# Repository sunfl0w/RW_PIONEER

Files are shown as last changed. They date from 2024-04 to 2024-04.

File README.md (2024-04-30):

# RW-Pioneer

RW-Pioneer is a computer project inspired by Ben Eater's [8-bit breadboard computer project](https://www.youtube.com/playlist?list=PLowKtXNTBypGqImE405J2565dvjafglHU) over at YouTube.
I always wanted to build my own crappy computer, and the Pioneer was my first such attempt.
The design is not perfect by any means, but it was the best one I could come up with after a few semesters of studying computer science.

**Note that the RW-Pioneer is a few years old by now and I only compiled old schematics, layouts and code for this repository.**
**I recently added a binary compatible Verilog model of the system with Verilator test suite and Vivado project files for the Nexys A7 board.**

## Content

This repository contains the following schematics and software components:

- RW-Pioneer schematics, paper explaining the architecture and KiCad design files (Schematic and RW_PIONEER_WHITEPAPER.pdf)
- RW-Pioneer Verilog model with Verilator test suite and Vivado project files for the NEXYS A7 board (VerilogModel)
- HEX-Module and 1602-Module schematics and KiCad design files (ExpansionModules)
- Instruction LUT generator for the instruction decoder memory IC of the system (InstructionLUTGenerator)
- Memory-Programmer host and programmer software sources, schematics and KiCad design files (MemoryProgrammer)
- Simple software emulator for the system (RWEMU)

## Licenses

The software and schematics are licensed under the permissive BSD 3-Clause License.

## Links

[Visit my personal website to see the Pioneer in action.](https://www.rechenwerke.com/projects/rw_pioneer)

## Gallery

Image of a prototype board I assembled a few years ago.

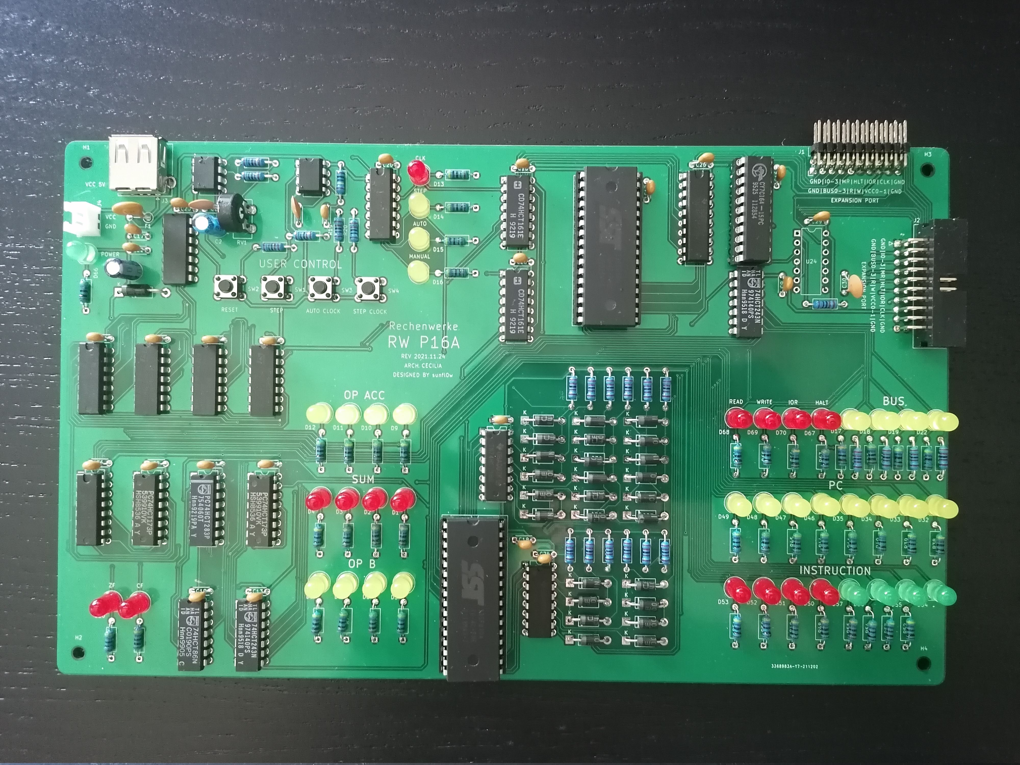
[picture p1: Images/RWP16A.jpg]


Image of the NEXYS A7 board running the RW-Pioneer Verilog model.



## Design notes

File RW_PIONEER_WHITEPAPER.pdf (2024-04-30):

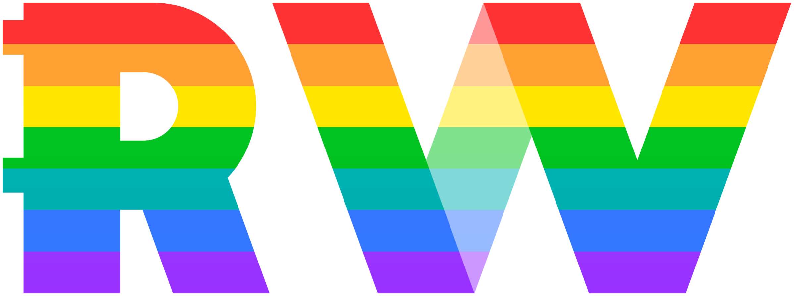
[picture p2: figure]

# Die Rechenwerke RW-Pioneer

### Luca Anthony Schwarz / Die Rechenwerke

### April 30, 2024, Hannover

1

www.rechenwerke.com

General information

The purpose of this paper is to provide an overview over the RW-Pioneer computer system. All implementation details in this paper only apply to the physical RW-Pioneer system implementation based on discrete integrated circuits and components. The Verilog-based version utilizes the same instruction set, but performs operations in three instead of two clock cycles. The changes were required to make the model synthesizable on FPGAs.

Contents

1 Architecture specification | 1
2 Hardware components | 6
3 Expansion port | 7
4 Expansion modules | 8
5 Programming | 8
6 Emulation | 9
7 Verilog model | 9
8 Schematics | 10
1 | Architecture specification
1.1 | General architecture description

RW-Pioneer is a 4-bit computer system that is based on the Harvard computer architecture. All mathematical operations are performed on 4-bit wide sets of binary data in the ALU. Wider operations are possible by using the carry flag of the previous operation. This requires strict instruction ordering, as multiple additions or subtraction operations must be executed consec-utively. RAM address space is split up into sixteen addresses. Each address corresponds to one 4-bit word of storage in RAM. Program memory consists of 256 bytes, with one instruction being encoded by two 4-bit words. The program counter (PC) can be altered by instructions to allow for jumps and branches. As memory access is only possible using immediate addresses, the system can not be considered general purpose and is not Turing-complete.

The architecture can be seen in the block diagram 1. The diagram shows all main components of the architecture with their respective connections and splits them into two groups (Step0 and Step1). Instructions are executed in two clock cycles. In the first cycle (Step0) the next instruction will be loaded into the instruction register and decoded by the instruction decoder which sets the control signal lines according to the loaded instruction. In the second cycle (Step1) the instruction is then executed and the step counter resets to zero while the program counter advances by 1 if no jump instruction was performed. Jump instructions write into the program counter directly without incrementing it by 1.

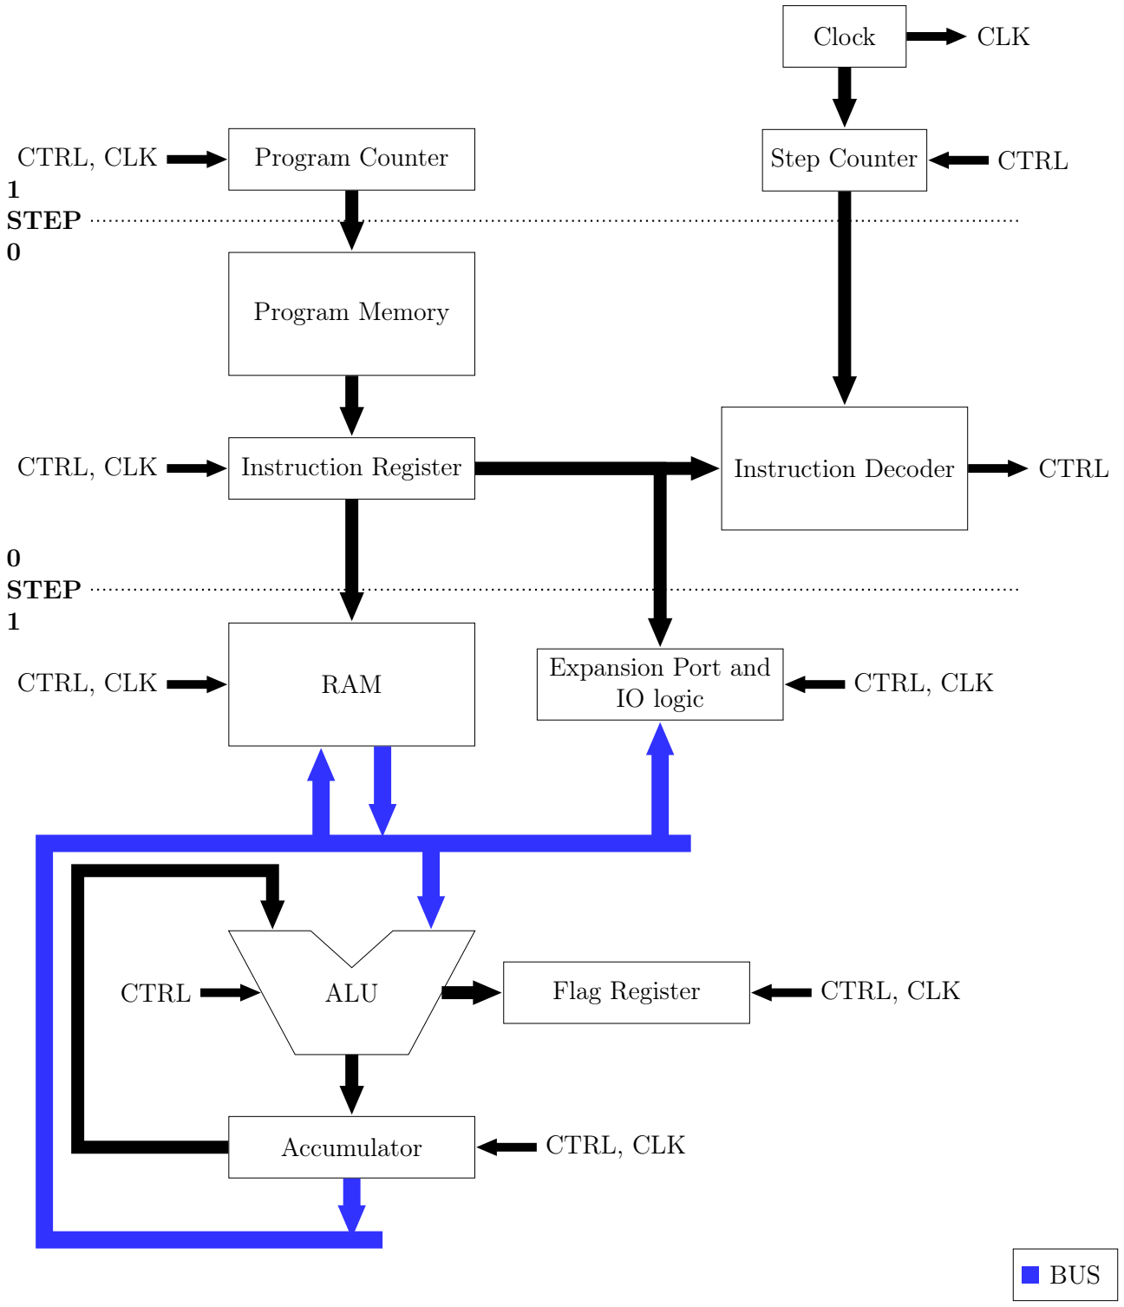
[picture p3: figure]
Program Counter; Program Memory; Instruction Register; Instruction Decoder; Step Counter; Clock; RAM; Expansion Port and; IO logic; ALU; Flag Register; Accumulator; CLK; CTRL; CTRL, CLK; 1 STEP 0; 0 STEP 1; BUS

Figure 1: DLC1 architecture block diagram

1.2 Instruction set

Instructions are encoded into one byte of data. The most significant word is called instruction code (IC) and the least significant word is called instruction value (IV). The instruction code defines the instruction type, and the instruction value is the immediate parameter of that instruction.
7 | 4 | 3 | 0
Instruction Code IC | Instruction Value IV

Figure 2: Instruction Bit Field

As four bits are used to encode an instruction’s code, a maximum of 16 different instructions are supported. The implemented instructions are listed in table 1. Not all instructions require an instruction value. It is advised to use an instruction value of 0xF in such cases.

RW-PIONEER instruction set

Instruction | IC | Functional description
LDI | 0x0 | ACC 7→IV
LDA | 0x1 | ACC 7→RAM[IV]
STOA | 0x2 | RAM[IV] 7→ACC
STOB | 0x3 | RAM[IV] 7→BUS
ADD | 0x4 | ACC 7→ACC + RAM[IV]
ADDI | 0x5 | ACC 7→ACC + IV
ADDC | 0x6 | ACC 7→ACC + RAM[IV] + CF
SUB | 0x7 | ACC 7→ACC − RAM[IV]
SUBI | 0x8 | ACC 7→ACC − IV
SUBC | 0x9 | ACC 7→ACC − RAM[IV] − CF
SJMP | 0xA | PCL 7→IV
JMP | 0xB | PCL 7→IV and PCH 7→ACC
BNEZ | 0xC | PCL 7→IV and PCH 7→ACC if ZF = LOW
BEZ | 0xD | PCL 7→IV and PCH 7→ACC if ZF = HIGH
HALT | 0xE | Halt program execution (set HLT signal HIGH)
NOOP | 0xF | Perform no operation

Table 1: RW-Pioneer instruction set

1.3 Micro operations

Instruction codes are interpreted by an instruction decoder. The decoder then supplies the ALU and the memory unit with appropriate control signals, so-called micro operations. Interestingly, the memory unit controls the instruction and random access memories, as well as the program counter. The instruction counter is enabled or disabled by the CE signal, and the system is halted by the HLT signal. The ALU performs the mathematical operations and controls the accumulator and flag registers. The control signals are influenced by the step counter, as the system requires two cycles per instruction. In step 0 a new instruction is loaded in all cases. Only in step 1 the fetched instruction is interpreted and executed. Conditional branches are only executed, if the stored zero flag value ZF is a match for the given branch instruction. For example, to take the branch on an BNEZ instruction, the ZF signal is required to be LOW. The internal control signals and micro operations are listed in table 2.

RW-Pioneer instruction to micro instruction look-up table
Instruction | Step | ZF | ALU | MEM | CE | HLT
X | 0 | X | ALU_NOOP | MEM_LDINSTRC | L | L
LDI | 1 | X | ALU_BUSTOACC | MEM_IVTOBUS | H | L
LDA | 1 | X | ALU_BUSTOACC | MEM_RAMTOBUS | H | L
STOA | 1 | X | ALU_ACCTOBUS | MEM_BUSTORAM | H | L
STOB | 1 | X | ALU_NOOP | MEM_BUSTORAM | H | L
ADD | 1 | X | ALU_ADD | MEM_RAMTOBUS | H | L
ADDI | 1 | X | ALU_ADD | MEM_IVTOBUS | H | L
ADDC | 1 | X | ALU_ADDC | MEM_RAMTOBUS | H | L
SUB | 1 | X | ALU_SUB | MEM_RAMTOBUS | H | L
SUBI | 1 | X | ALU_SUB | MEM_IVTOBUS | H | L
SUBC | 1 | X | ALU_SUBC | MEM_RAMTOBUS | H | L
SJMP | 1 | X | ALU_NOOP | MEM_SJMP | L | L
JMP | 1 | X | ALU_NOOP | MEM_JMP | L | L
BNEZ | 1 | L | ALU_NOOP | MEM_JMP | L | L
BNEZ | 1 | H | ALU_NOOP | MEM_NOOP | H | L
BEZ | 1 | L | ALU_NOOP | MEM_NOOP | H | L
BEZ | 1 | H | ALU_NOOP | MEM_JMP | L | L
HALT | 1 | X | ALU_NOOP | MEM_NOOP | L | H
NOOP | 1 | X | ALU_NOOP | MEM_NOOP | H | L

Table 2: RW-Pioneer instruction to micro instruction look-up table

The ALU is supplied with a single micro operation per step by the instruction decoder. The micro operation is supplied as a 3-bit wide signal (AIC), which is then interpreted by the ALU as described in table 3. The ALU micro instruction decoder directly controls ALU operation by using six internal control signals. The signals AI0 and AI1 define, whether an addition or a subtraction is performed and if this operation uses the currently stored carry flag. ACCTBUS controls if the accumulator value is to be sent on the system bus. SSACC defines the accumulator source. This can be the system bus, or the result of the ALU. EACC disables the accumulator register and FI disables storing the zero and the carry flags for an operation. The memory unit is supplied with a single micro operation per step by the instruction

RW-Pioneer ALU micro instructions
Micro instruction | AIC | AI1 | AI0 | ACCTBUS | SSACC | EACC | FI
ALU_ADD | 0x0 | L | L | H | L | L | L
ALU_ADDC | 0x1 | L | H | H | L | L | L
ALU_SUB | 0x2 | H | L | H | L | L | L
ALU_SUBC | 0x3 | H | H | H | L | L | L
ALU_BUSTOACC | 0x4 | H | H | H | H | L | H
ALU_ACCTOBUS | 0x5 | H | H | L | H | H | H
ALU_NOOP | 0x6 | H | H | H | H | H | H
ALU_NOOP | 0x7 | H | H | H | H | H | H

Table 3: RW-Pioneer ALU micro instructions

decoder. The micro operation is supplied as a 3-bit wide signal (MIC), which is then interpreted by the memory unit as described in table 4. The memory unit micro instruction decoder directly controls memory, bus and program counter operations by using six internal control signals. JL disables loading the least significant four bits of the program counter from the instruction value of the current instruction. JH disables loading the most significant four bits of the program counter from the accumulator. LI disables loading the next instruction. This is only used in
step 0 to load the next instruction. WERAM sets the write enable signal of RAM. CERAM sets the chip enable signal of RAM. IVTBUS disables putting the instruction value of the current instruction to the system bus.

RW-Pioneer memory micro instructions
Micro instruction | MIC | JL | JH | LI | WERAM | CERAM | IVTBUS
MEM_SJMP | 0x0 | L | H | H | H | H | H
MEM_JMP | 0x1 | L | L | H | H | H | H
MEM_BUSTORAM | 0x2 | H | H | H | L | L | H
MEM_RAMTOBUS | 0x3 | H | H | H | H | L | H
MEM_IVTOBUS | 0x4 | H | H | H | H | H | L
MEM_LDINSTRC | 0x5 | H | H | L | H | H | H
MEM_NOOP | 0x6 | H | H | H | H | H | H
MEM_NOOP | 0x7 | H | H | H | H | H | H

Table 4: RW-Pioneer memory micro instructions

2 Hardware components

RW-Pioneer was designed with simplicity as the primary goal. Therefore, commonly available components were chosen for physical implementation. For timing, the 555 timer ICs were used. Program memory and the instruction decoder’s look-up table use the SST39SD010A IC. It is a cheap parallel FLASH IC that is also easy to program using microcontrollers. Both memories should never be directly soldered to the PCB, as sockets make programming the memory ICs way easier. The RAM is realized by the CY7C164 chip, which is the only rare component in the whole design. All logic functions are implemented with the 74HC-Series and 74HCT-Series logic chips. 74LS ICs are not supported, but might still work.
Passive components can be chosen freely as long as the correct values are used. For example, the 1N4001 diodes may also be replaced by 1N4007 diodes or comparable ones if necessary, as long as the forward voltage drop remains at roughly 0.7 volts. The resistor values for all resistors used in conjunction with LEDs may be chosen freely as long as the resistor value is high enough. When using different color LEDs different values for different colors might be used to keep a balance of apparent brightness between them.

3 Expansion port

The RW-Pioneer provides an expansion port (also called user port) to communicate with external circuitry. The pin assignments of the expansion port are listed in table 5. The port allows access to the instruction value of the current instruction and also to the data on the system bus. Instructions interfacing with system RAM can be identified by reading the values of the R, W and IOR signals. Access is also provided to the MR, HLT and CLK signals. Sending data and receiving data over the port is done via memory mapping. When the system writes data to memory W will be HIGH and when reading R will be HIGH. IOR is HIGH when main memory is accessed in the address range 11xx2. All signals provide by the port are 5V CMOS compatible. The expansion port allows for powering the connected external device, if the power requirement does not exceed the capabilities of the system’s power supply.

RW-Pioneer expansion port pin assignment
Pins | Function
1, 2, 19, 20 | GND
15, 17 | VCC
4, 6, 8, 10 | IV of current instruction from LSB to MSB
3, 5, 7, 9 | BUS from LSB to MSB
11 | RE. HIGH when reading from RAM
12 | MR. HIGH if reset signal provided
13 | WR. HIGH when writing to RAM
14 | HLT. HIGH when halt signal is provided
16 | IOR. HIGH when RAM is accessed from addresses 11002 to 11112
18 | CLK. Direct link to the CLK signal

Table 5: RW-Pioneer expansion port pin assignment

3.1 Sending data over the expansion port

Sending data should be implemented via memory mapping. To showcase this a 4-bit register (74HC173) is connected to the expansion port which is mapped to RAM address 11112. The CLK signal is connected to the CLK input of the 4-bit register. The enable signal (E) (active

HIGH) is connected to logic that computes E = IV0 ∧ IV1 ∧ IOR and the input data lines (D0 to D3) of the register are connected to BUS (BUS0 to BUS3). When the system executes the STOA instruction with IV = 11112, the values in the accumulator will be written to RAM at address IV. The input E of the register will transition to HIGH, so the register is enabled. Then the CLK signal transitions to HIGH and the register will store the value that was on the BUS (which was also written to RAM). In conclusion, this setup links the register connected via the expansion port to a RAM address. Expansions like a simple LCD can be controlled in this way.

3.2 Receiving data over the expansion port

Receiving data should be implemented via memory mapping like sending data. The difference to sending is, that receiving data requires the STOB instruction, to first store the data at a given address in RAM. Clever memory mapping schemes would allow for direct accessing of external data, but the RW-Pioneer does not have such functionality. To showcase receiving data, a 4-bit register (74HC173) is connected to the expansion port, which is mapped to address memory address 11112. The CLK signal is connected to the CLK input of the 4-bit register. The output enable signal OE (active HIGH) is connected to logic that computes OE = IV0 ∧ IV1 ∧ IOR and the output data lines (Q0

| to Q3 ) of the register are connected to BUS (BUS0 to BUS3).
When the system executes the STOB instruction with IV = 11112, the values on the BUS will be written to RAM at address IV. The OE input of the register will transition to HIGH, so the register will write its stored value to the BUS. As a result, RAM will store the register’s stored value at the address 11112. In conclusion, this setup links the register connected via the expansion port to a RAM address. Expansions like a very simple sensor module can be realized using this memory mapping method.
4 | Expansion modules
4.1 | HEX-Module

The HEX-Module provides the system with four seven-segment displays to display four-digit hexadecimal values. Each digit’s value is dependent on the value the accompanying register stores. The registers are directly writable by the RW-Pioneer.

4.2 1602-Module

The 1602-Module expands the system with a 1602-LCD, that is completely controllable by the RW-Pioneer. With the module, it is quite easy to display small texts and numbers.

5 Programming

The system is programmed by writing instructions to the instruction memory chip. A simple memory programmer called Memory-Programmer is provided with the RW-Pioneer to fulfill this task. The programmer employs an ATmega328 microcontroller in the form of an Arduino Nano and is controlled by a USB host through a simple host software. The host computer simply specifies a hex file to program to memory, and the memory programmer will complete this task in a few seconds.

6 Emulation

A simple emulation software called RWEMU for the RW-Pioneer is supplied alongside schematics and this document. With this emulator, programs can be tested before running them on a physical design. This helps to eliminate errors introduced by the programmer but can also be used to verify the physical design by comparing emulation and measured/observed results.

7 Verilog model

Parts of the RW-Pioneer system are modeled in the Verilog HDL. This model is supplied alongside this document and implements all essential components, except the manual clocking mechanism and the expansion port. The model and the physical implementation are binary compatible.

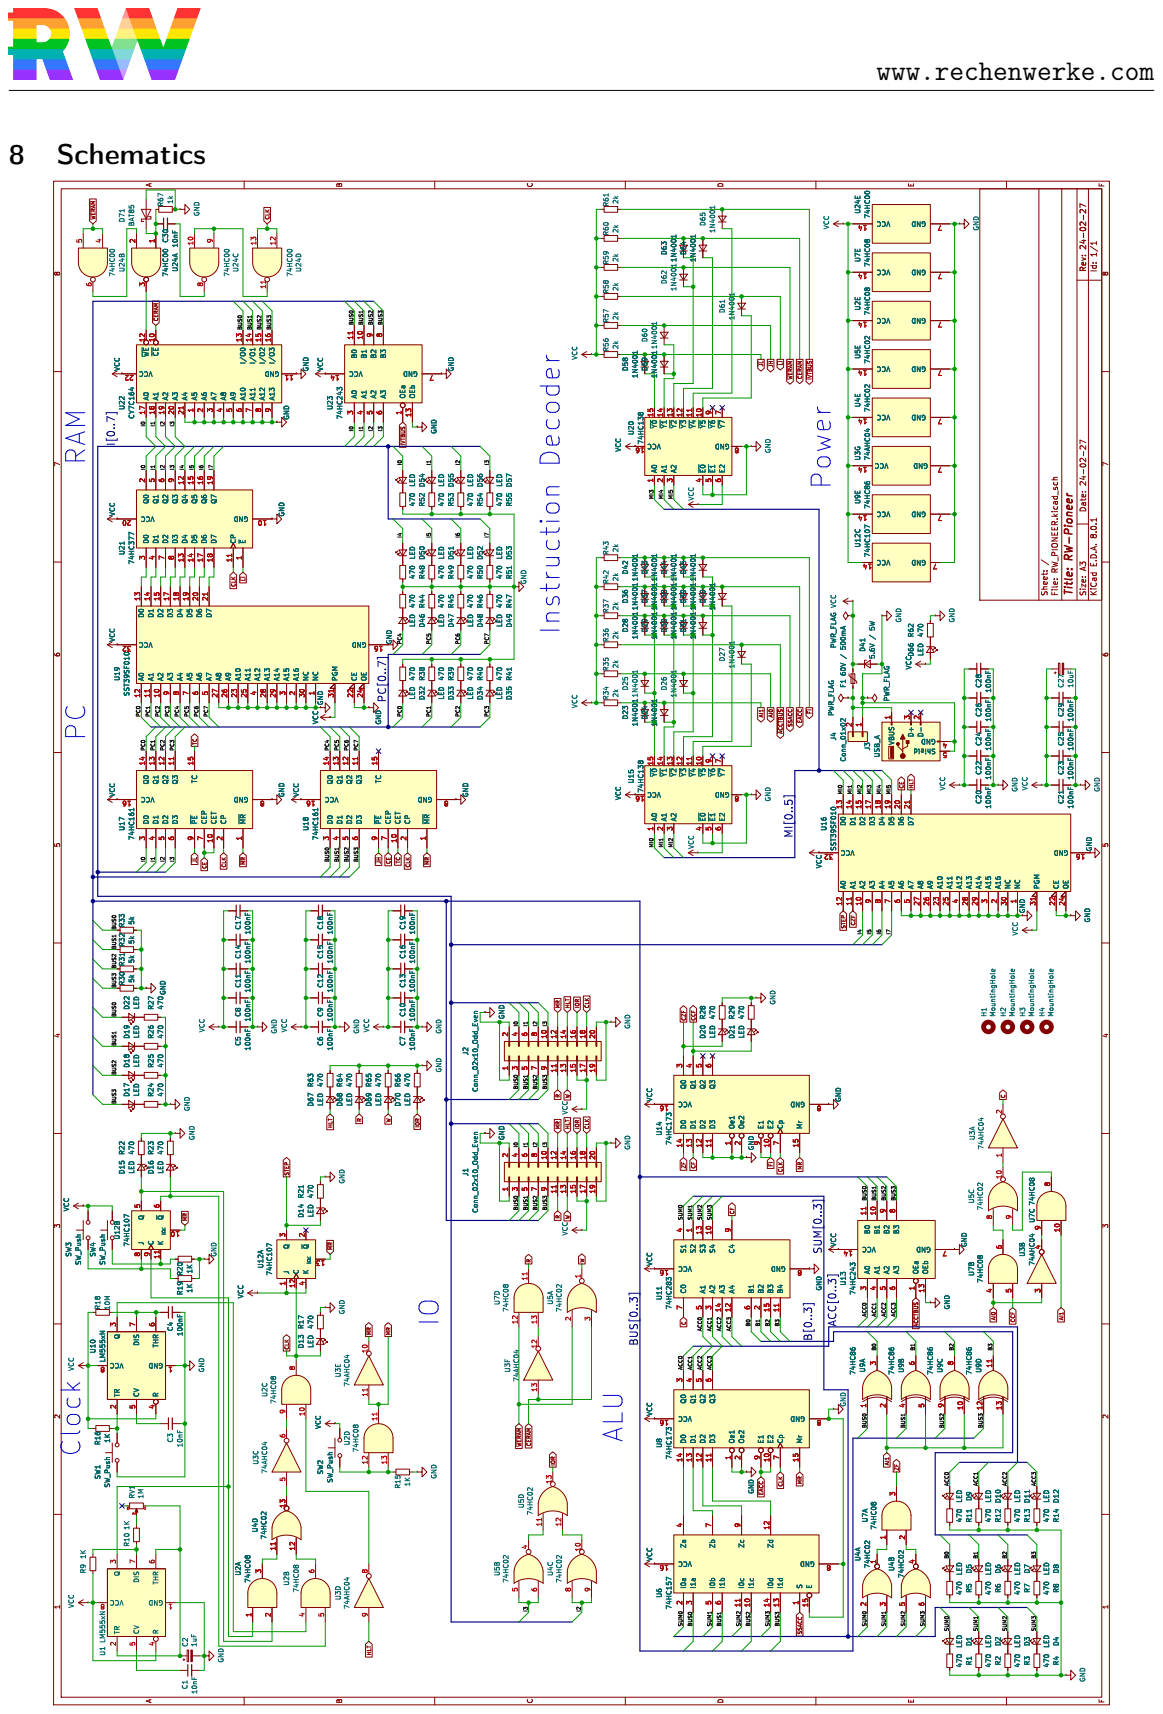
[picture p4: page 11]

F Date: 24-02-27 KiCad E.D.A. 8.0.1 Rev: 24-02-27 Size: A3

~{FI} CLK HLT CLK

2k VCC GND VCC 14 GND

Id: 1/1 Title: RW-Pioneer File: RW_PIONEER.kicad_sch Sheet: / PWR_FLAG

74HC377~{E} 1 GND 10 CP 11 Q4 12 D4 13 D5 14 Q5 15 Q6 16 D6 17 D7 18 Q7 19 Q0 2 VCC 20 D0 3 D1 4 Q1 5 Q2 6 D2 7 D3 8 Q3 9 VCC GND GND

~{JH} ~{LI} ~{CERAM} ~{JL} ~{WERAM} ~{IVTBUS}

U19 SST39SF010 GND 16 VCC 32 NC 1 A2 10 A1 11 A0 12 D0 13 D1 14 D2 15 D3 17 D4 18 D5 19 A16 2 D6 20 D7 21 CE 22 A10 23 OE 24 A11 25 A9 26 A8 27 A13 28 A14 29 A15 3 NC 30 PGM 31 A12 4 A7 5 A6 6 A5 7 A4 8 A3 9 U23

F1 60V / 500mA GND GND VCC 14 GND

100nF GND 16 VCC 32 NC 1 A2 10 A1 11 A0 12 D0 13 D1 14 D2 15 D3 17 D4 18 D5 19 A16 2 D6 20 D7 21 CE 22 A10 23 OE 24 A11 25 A9 26 A8 27 A13 28 A14 29 A15 3 NC 30 PGM 31 A12 4 A7 5 A6 6 A5 7 A4 8 A3 9 U19 SST39SF010 C15

~{MR} 1 CET 10 Q3 11 Q2 12 Q1 13 Q0 14 TC 15 VCC 16 CP 2 D0 3 D1 4 D2 5 D3 6 CEP 7 GND

74HC161 ~{MR} 1 CET 10 Q3 11 Q2 12 Q1 13 Q0 14 TC 15 VCC 16 CP 2 D0 3 D1 4 D2 5 D3 6 CEP 7 GND

VCC GND 16 VCC 32 NC 1 A2 10 A1 11 A0 12 D0 13 D1 14 D2 15 D3 17 D4 18 D5 19 A16 2 D6 20 D7 21 CE 22 A10 23 OE 24 A11 25 A9 26 A8 27 A13 28 A14 29 A15 3 NC 30 PGM 31 A12 4 A7 5 A6 6 A5 7 A4 8 A3 9 U16 SST39SF010

U16 SST39SF010 GND 16 VCC 32 NC 1 A2 10 A1 11 A0 12 D0 13 D1 14 D2 15 D3 17 D4 18 D5 19 A16 2 D6 20 D7 21 CE 22 A10 23 OE 24 A11 25 A9 26 A8 27 A13 28 A14 29 A15 3 NC 30 PGM 31 A12 4 A7 5 A6 6 A5 7 A4 8 A3 9 GND GND

100nF GND Oe1 1 E2 10 D3 11 D2 12 D1 13 D0 14 Mr 15 VCC 16 Oe2 2 Q0 3 Q1 4 Q2 5 Q3 6 Cp 7 GND

H1 MountingHole H2 MountingHole H4 MountingHole VCC

74HC173 VCC OEa 1 B1 10 B0 11 OEb 13 VCC 14 A0 3 A1 4 A2 5 A3 6 GND

VCC GND GND Oe1 1 E2 10 D3 11 D2 12 D1 13 D0 14 Mr 15 VCC 16 Oe2 2 Q0 3 Q1 4 Q2 5 Q3 6 Cp 7 GND

74HC173 Oe1 1 E2 10 D3 11 D2 12 D1 13 D0 14 Mr 15 VCC 16 Oe2 2 Q0 3 Q1 4 Q2 5 Q3 6 Cp 7 GND

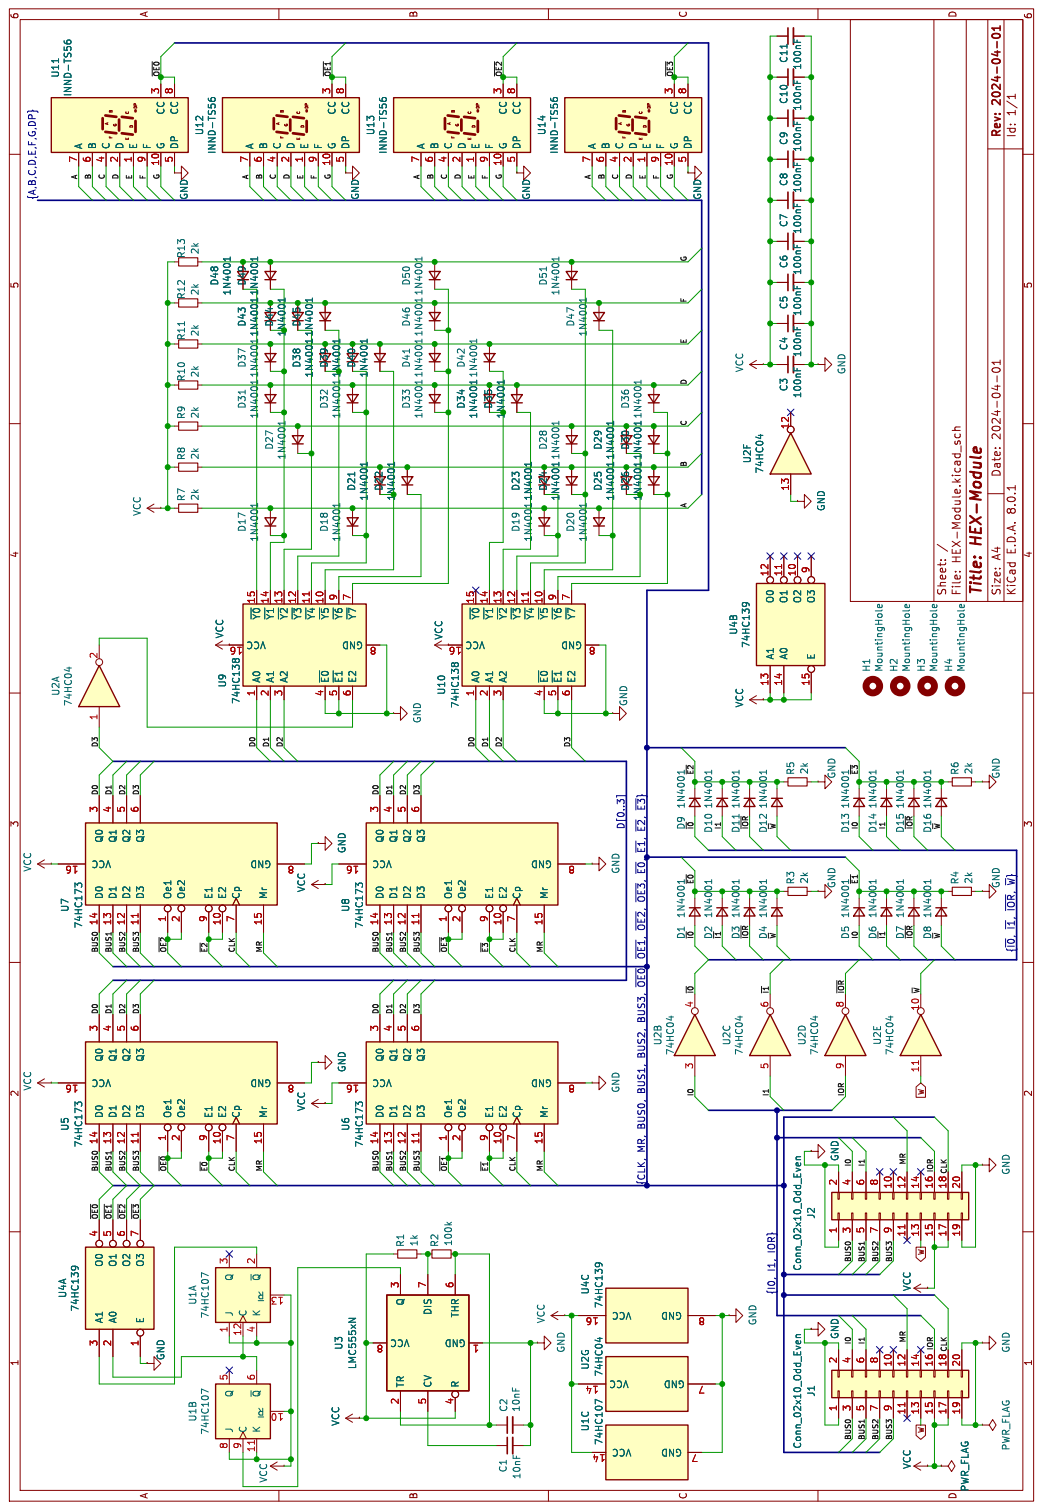
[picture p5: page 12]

D Date: 2024-04-01 KiCad E.D.A. 8.0.1 Rev: 2024-04-01 Size: A4

Id: 1/1 Title: HEX-Module

1N4001 VCC GND Oe1 1 E2 10 D3 11 D2 12 D1 13 D0 14 Mr 15 VCC 16 Oe2 2 Q0 3 Q1 4 Q2 5 Q3 6 Cp 7 GND

1N4001 GND Oe1 1 E2 10 D3 11 D2 12 D1 13 D0 14 Mr 15 VCC 16 Oe2 2 Q0 3 Q1 4 Q2 5 Q3 6 Cp 7 GND

File: HEX-Module.kicad_sch Sheet: / GND

2k D16 1N4001 H1 MountingHole H2 MountingHole H3 MountingHole H4 MountingHole VCC

VCC GND Oe1 1 E2 10 D3 11 D2 12 D1 13 D0 14 Mr 15 VCC 16 Oe2 2 Q0 3 Q1 4 Q2 5 Q3 6 Cp 7 GND

74HC173Oe1 1 E2 10 D3 11 D2 12 D1 13 D0 14 Mr 15 VCC 16 Oe2 2 Q0 3 Q1 4 Q2 5 Q3 6 Cp 7 GND

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

J1 Conn_02x10_Odd_Even GND GND VCC 14 GND

4 CV 5 THR 6 DIS 7 VCC

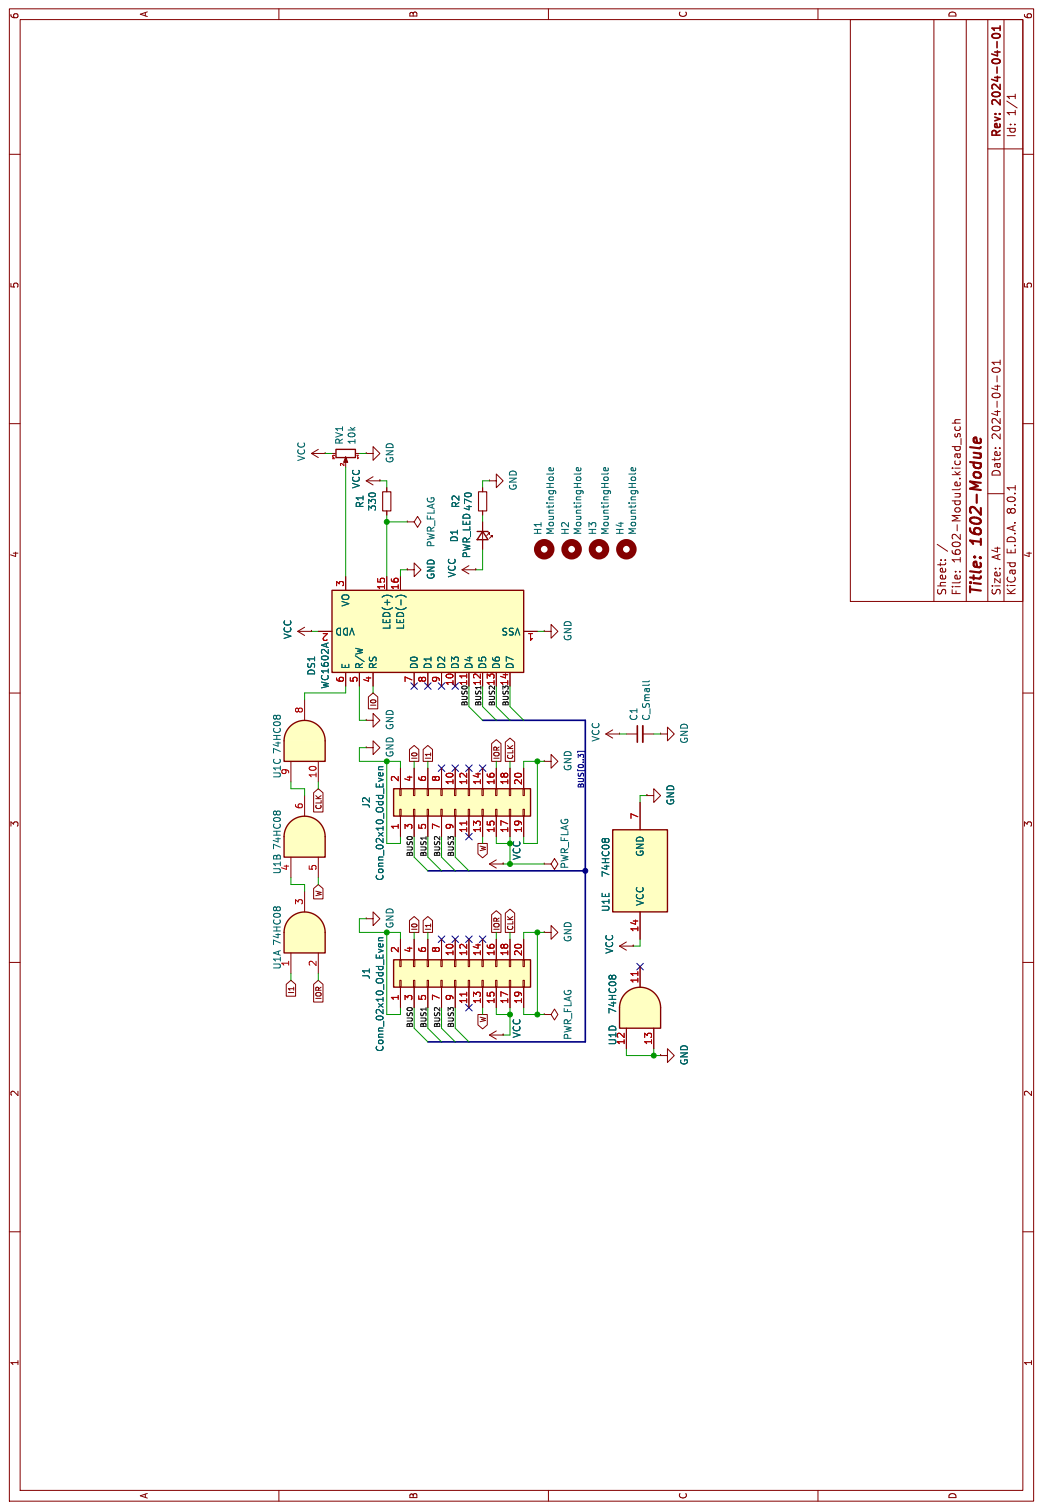
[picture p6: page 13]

D Date: 2024-04-01 KiCad E.D.A. 8.0.1 Rev: 2024-04-01 Size: A4

H1 MountingHole H2 MountingHole H3 MountingHole H4 MountingHole VCC GND

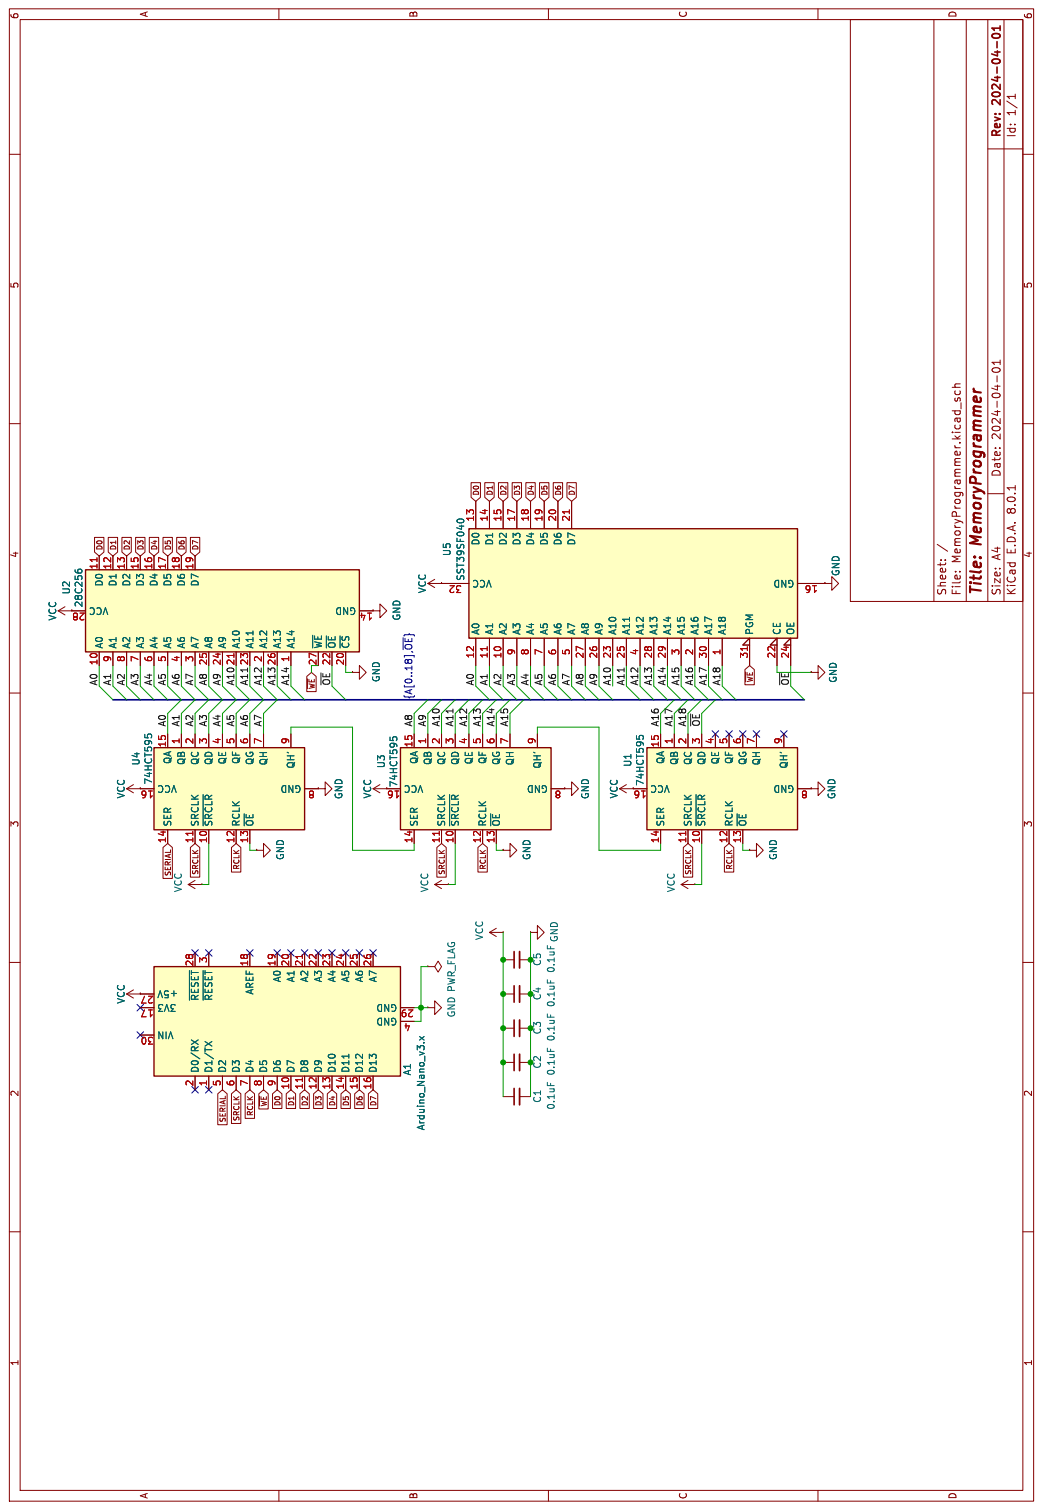
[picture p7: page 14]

D Date: 2024-04-01 KiCad E.D.A. 8.0.1 Rev: 2024-04-01 Size: A4

Id: 1/1 Title: MemoryProgrammer File: MemoryProgrammer.kicad_sch Sheet: / C2

28C256 VCCGND 16 VCC 32 A18 1 A2 10 A1 11 A0 12 D0 13 D1 14 D2 15 D3 17 D4 18 D5 19 A16 2 D6 20 D7 21 CE 22 A10 23 OE 24 A11 25 A9 26 A8 27 A13 28 A14 29 A15 3 A17 30 PGM 31 A12 4 A7 5 A6 6 A5 7 A4 8 A3 9 U5 SST39SF040 GND

U5 SST39SF040 GND 16 VCC 32 A18 1 A2 10 A1 11 A0 12 D0 13 D1 14 D2 15 D3 17 D4 18 D5 19 A16 2 D6 20 D7 21 CE 22 A10 23 OE 24 A11 25 A9 26 A8 27 A13 28 A14 29 A15 3 A17 30 PGM 31 A12 4 A7 5 A6 6 A5 7 A4 8 A3 9 GND GND GND GND GND GND

A14 1 A0 10 D0 11 D1 12 D2 13 GND 14 D3 15 D4 16 D5 17 D6 18 D7 19 A12 2 ~{CS} 20 A10 21 ~{OE} 22 A11 23 A9 24 A8 25 A13 26 ~{WE} 27 VCC 28 A7 3 A6 4 A5 5 A4 6 A3 7 A2 8 A1 9 U2

28C256 A14 1 A0 10 D0 11 D1 12 D2 13 GND 14 D3 15 D4 16 D5 17 D6 18 D7 19 A12 2 ~{CS} 20 A10 21 ~{OE} 22 A11 23 A9 24 A8 25 A13 26 ~{WE} 27 VCC 28 A7 3 A6 4 A5 5 A4 6 A3 7 A2 8 A1 9 U4

{A[0..18],~{OE}} A0 A3 A7A12 A1A6A7A8A12 A13 A17 A18 A10 A11 A5A11 A5 ~{OE} A8 A10 A9A16 ~{OE} A6A4A5 A7A14 A15 A0 A4 A2A3 GND

~{WE} D4 D5 ~{WE} D6 SRCLKD2 D3 SERIAL SRCLK

VCC QB 1 ~{SRCLR} 10 SRCLK 11 RCLK 12 ~{OE} 13 SER 14 QA 15 VCC 16 QC 2 QD 3 QE 4 QF 5 QG 6 QH 7 GND

74HCT595 QB 1 ~{SRCLR} 10 SRCLK 11 RCLK 12 ~{OE} 13 SER 14 QA 15 VCC 16 QC 2 QD 3 QE 4 QF 5 QG 6 QH 7 GND

GND GND GND QB 1 ~{SRCLR} 10 SRCLK 11 RCLK 12 ~{OE} 13 SER 14 QA 15 VCC 16 QC 2 QD 3 QE 4 QF 5 QG 6 QH 7 GND

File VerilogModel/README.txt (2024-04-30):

The 'Model' directory contains the Verilog model of the RW-Pioneer.
'RW_PIONEER_Vivado' contains a Vivado project file for the NEXYS A7 board to run the model on FPGA hardware.
'Programs' contains a memory file with a program to run when implementing the design on the NEXYS A7.

Run make test in the 'Model' directory to run a full the of the RW-Pioneer model using Verilator.
Note that google test must be installed to run the tests.

NOTICE: When running the test comment out the line that says '`define NEXYSA7' in 'Model/rtl/defines.vh'. When synthesizing the model for the NEXYSA7 uncomment the line.

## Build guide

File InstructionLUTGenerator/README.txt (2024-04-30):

Simple program to generate a binary file with the contents of the instruction decoder look-up table.
The table needs to be programmed to the instruction decoder FLASH IC for the system to function.

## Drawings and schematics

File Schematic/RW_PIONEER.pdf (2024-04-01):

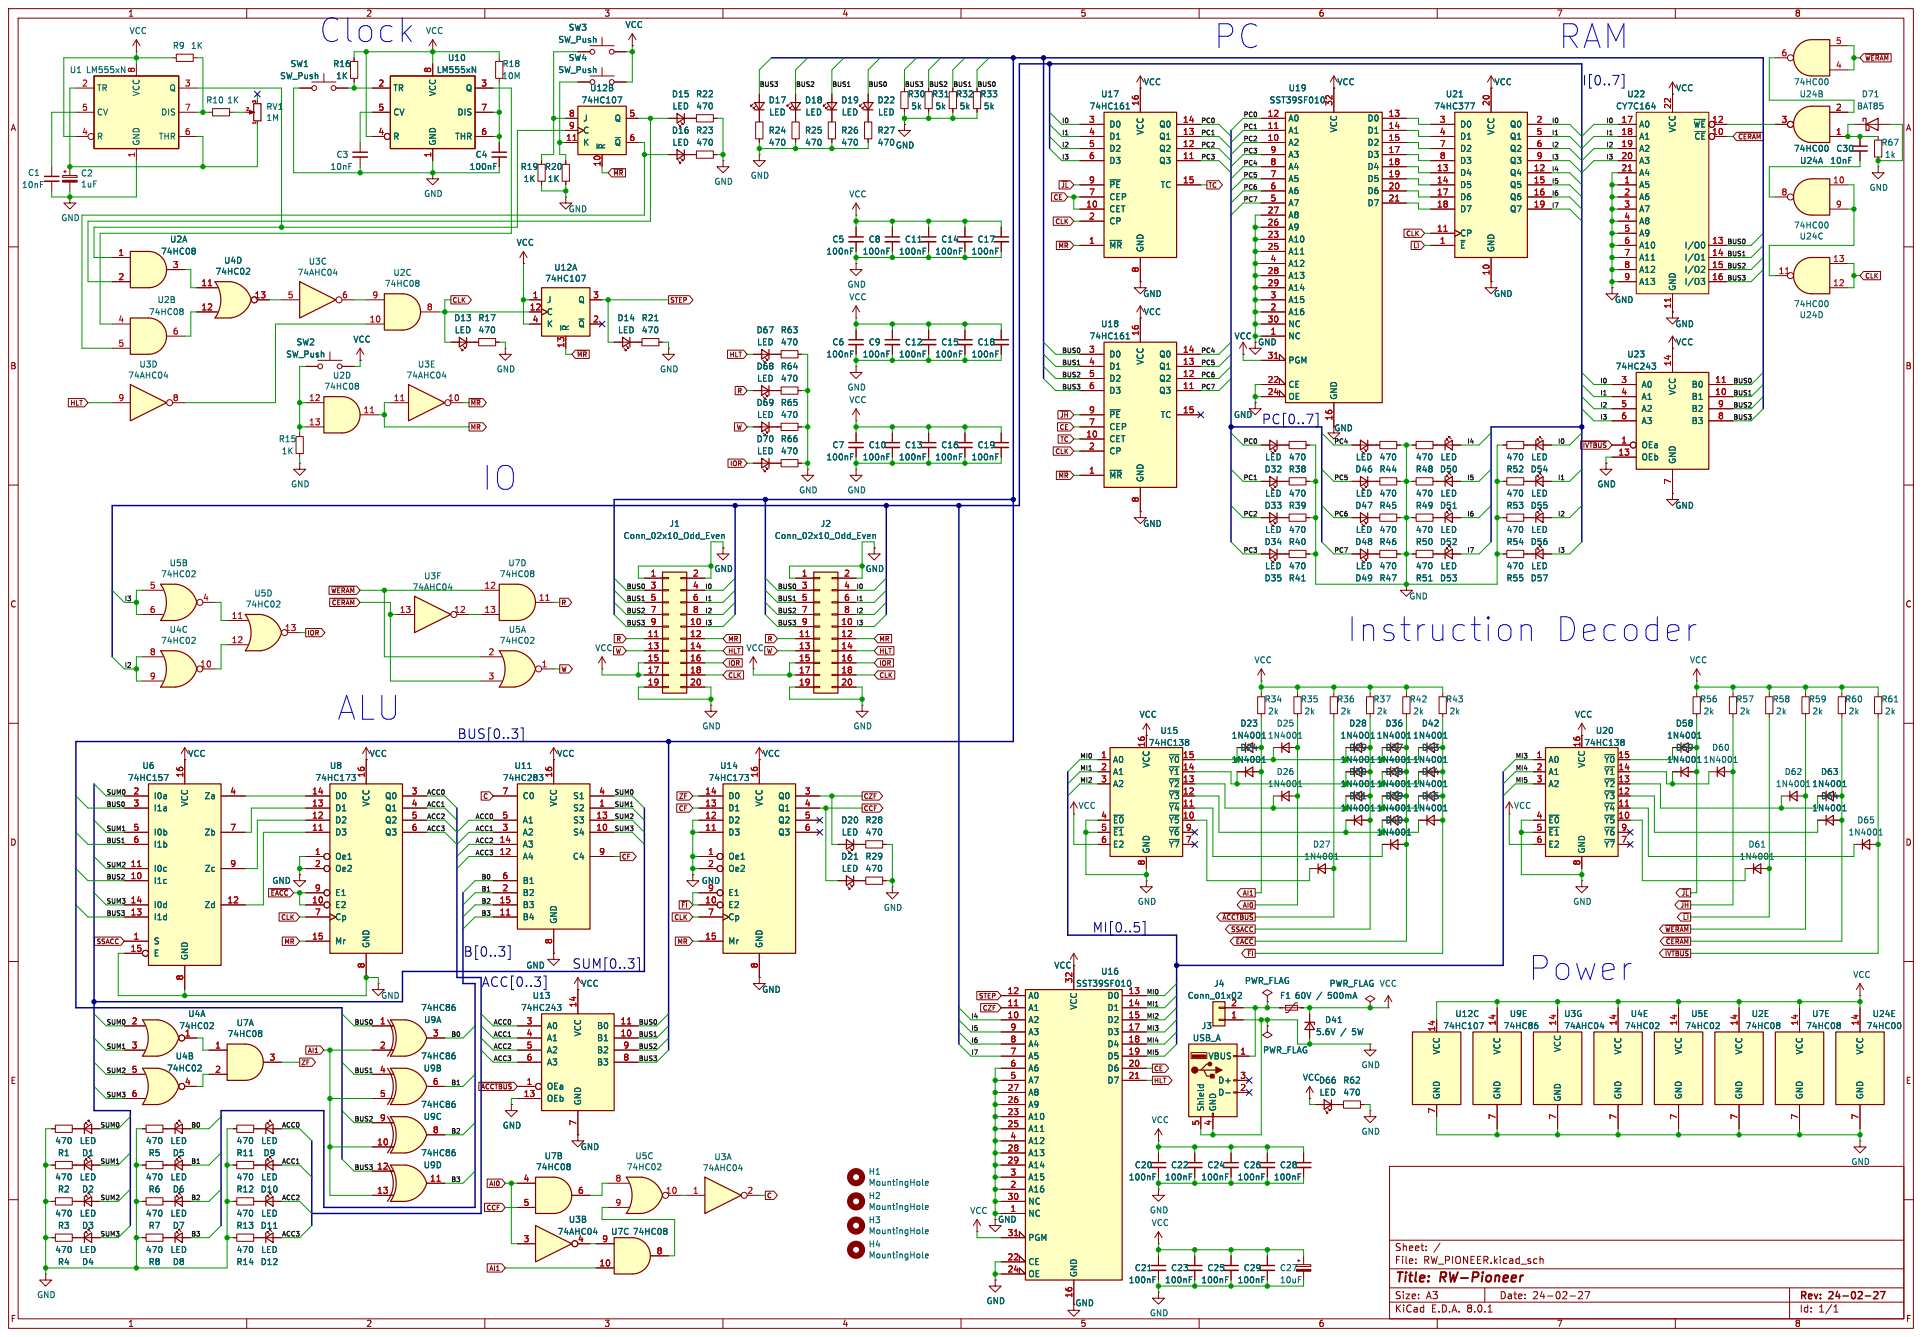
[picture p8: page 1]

~{JH} ~{LI} ~{CERAM} ~{JL} ~{WERAM} ~{IVTBUS}
Power

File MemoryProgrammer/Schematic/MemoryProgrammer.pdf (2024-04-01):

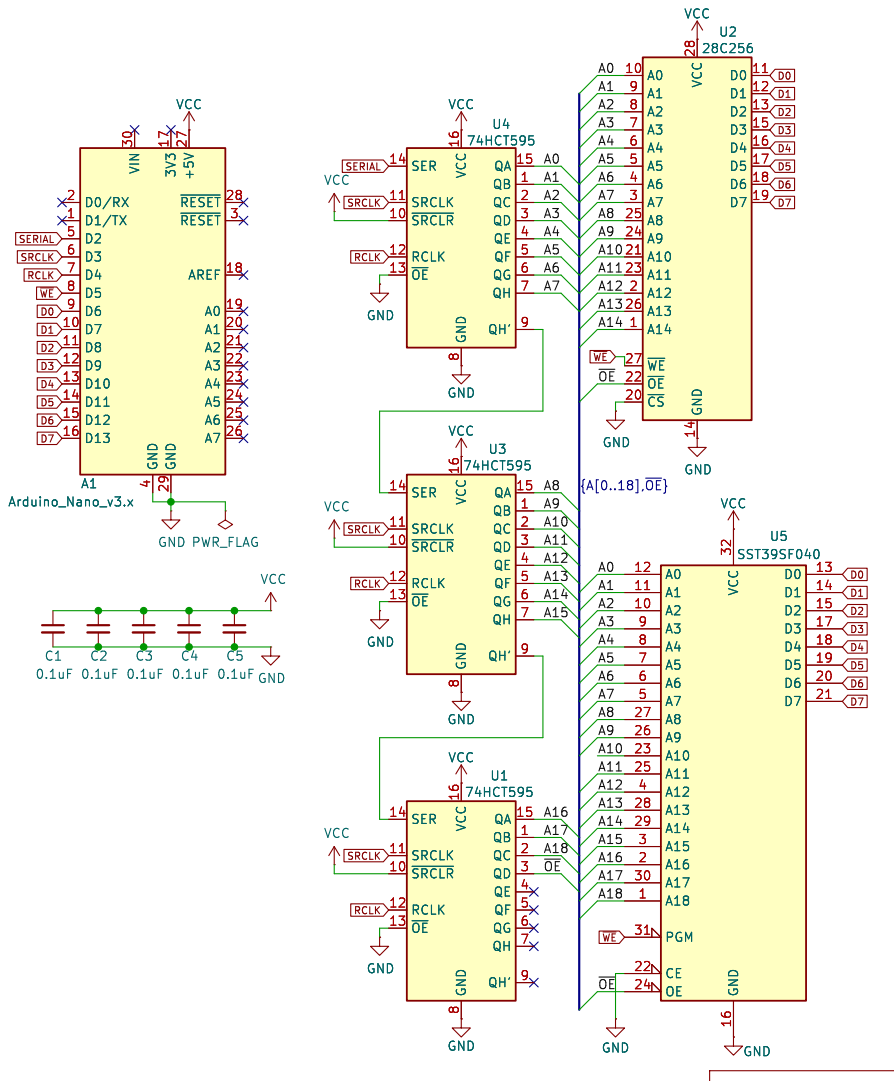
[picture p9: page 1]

Id: 1/1 Title: MemoryProgrammer File: MemoryProgrammer.kicad_sch Sheet: / C2

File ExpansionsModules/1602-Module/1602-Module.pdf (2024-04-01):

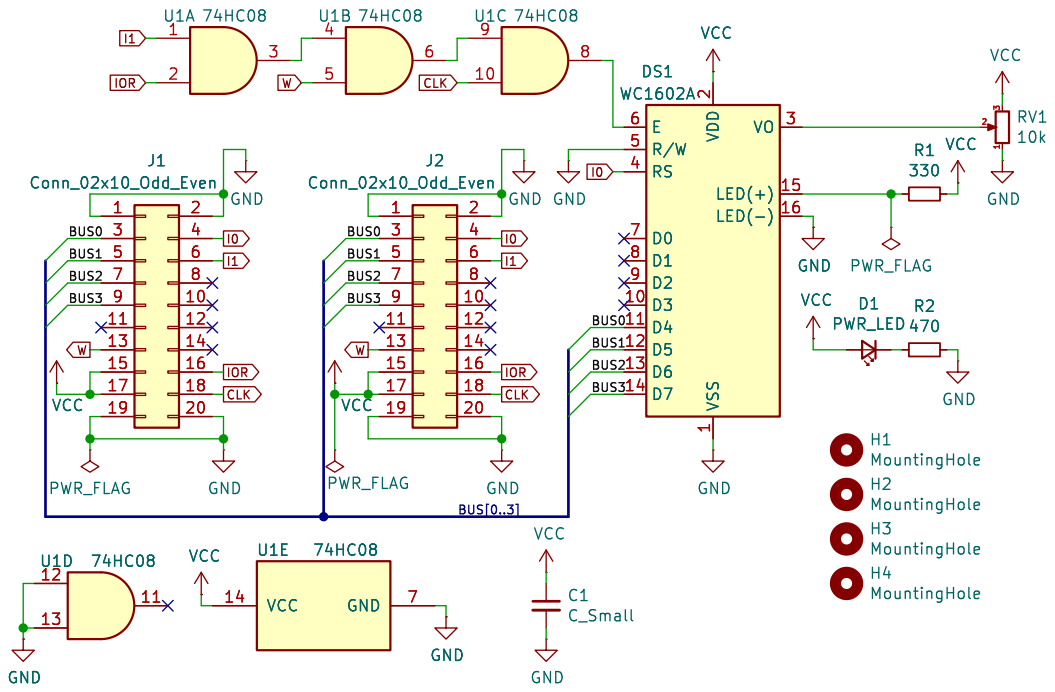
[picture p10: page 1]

H2 MountingHole H3 MountingHole H4 MountingHole H1 MountingHole GND

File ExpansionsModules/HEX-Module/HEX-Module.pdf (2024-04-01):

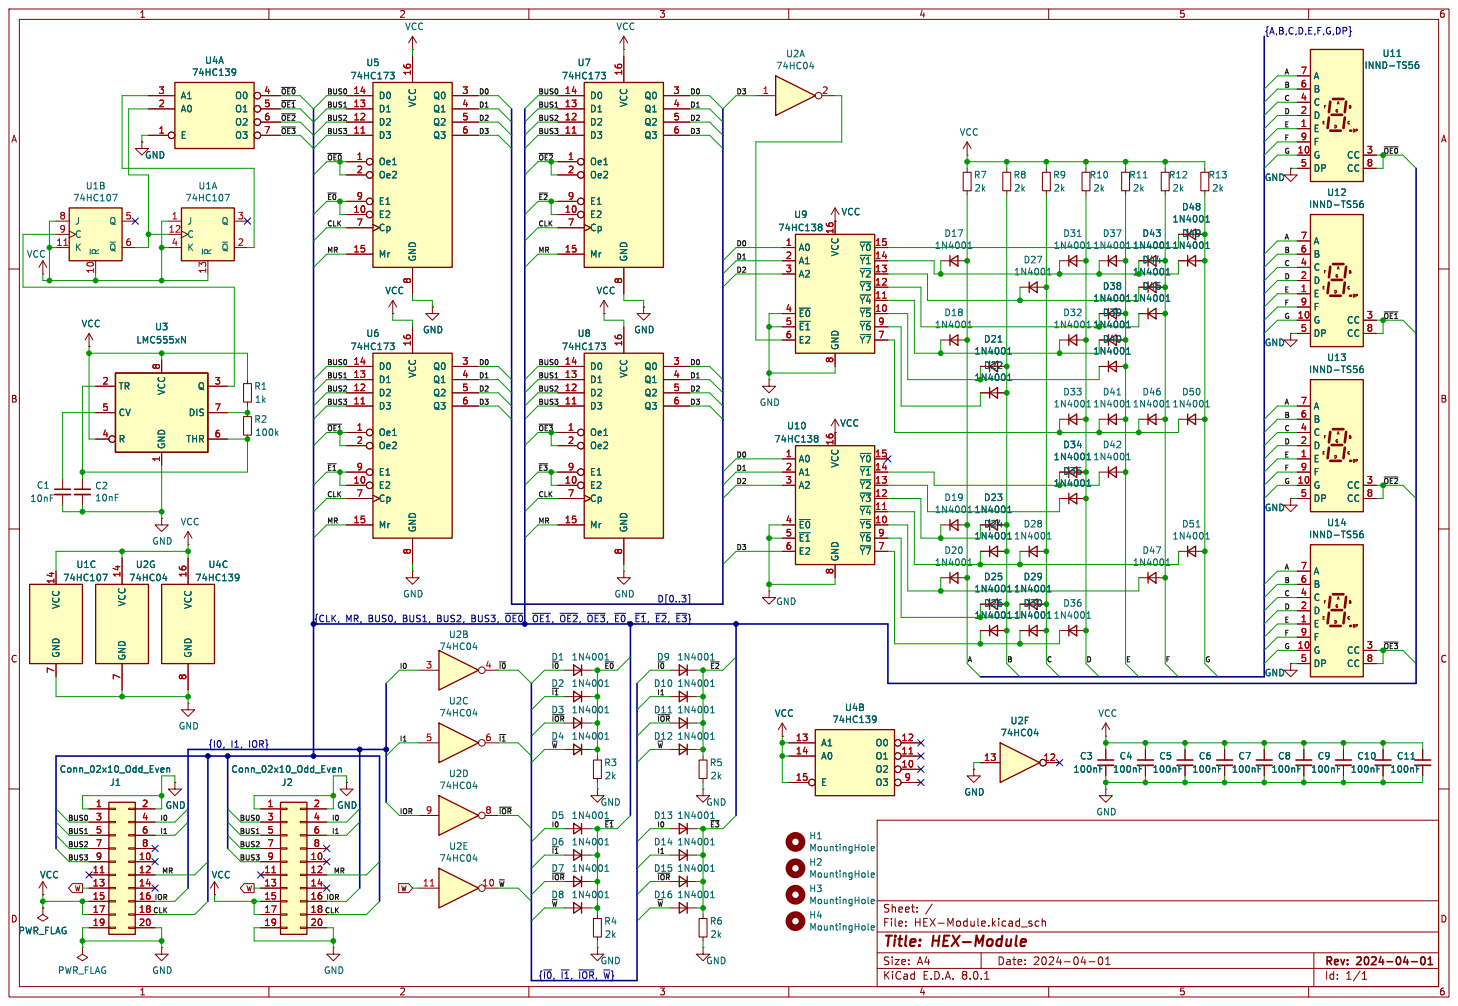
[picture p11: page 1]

File: HEX-Module.kicad_sch Sheet: / GND

Id: 1/1 Title: HEX-Module

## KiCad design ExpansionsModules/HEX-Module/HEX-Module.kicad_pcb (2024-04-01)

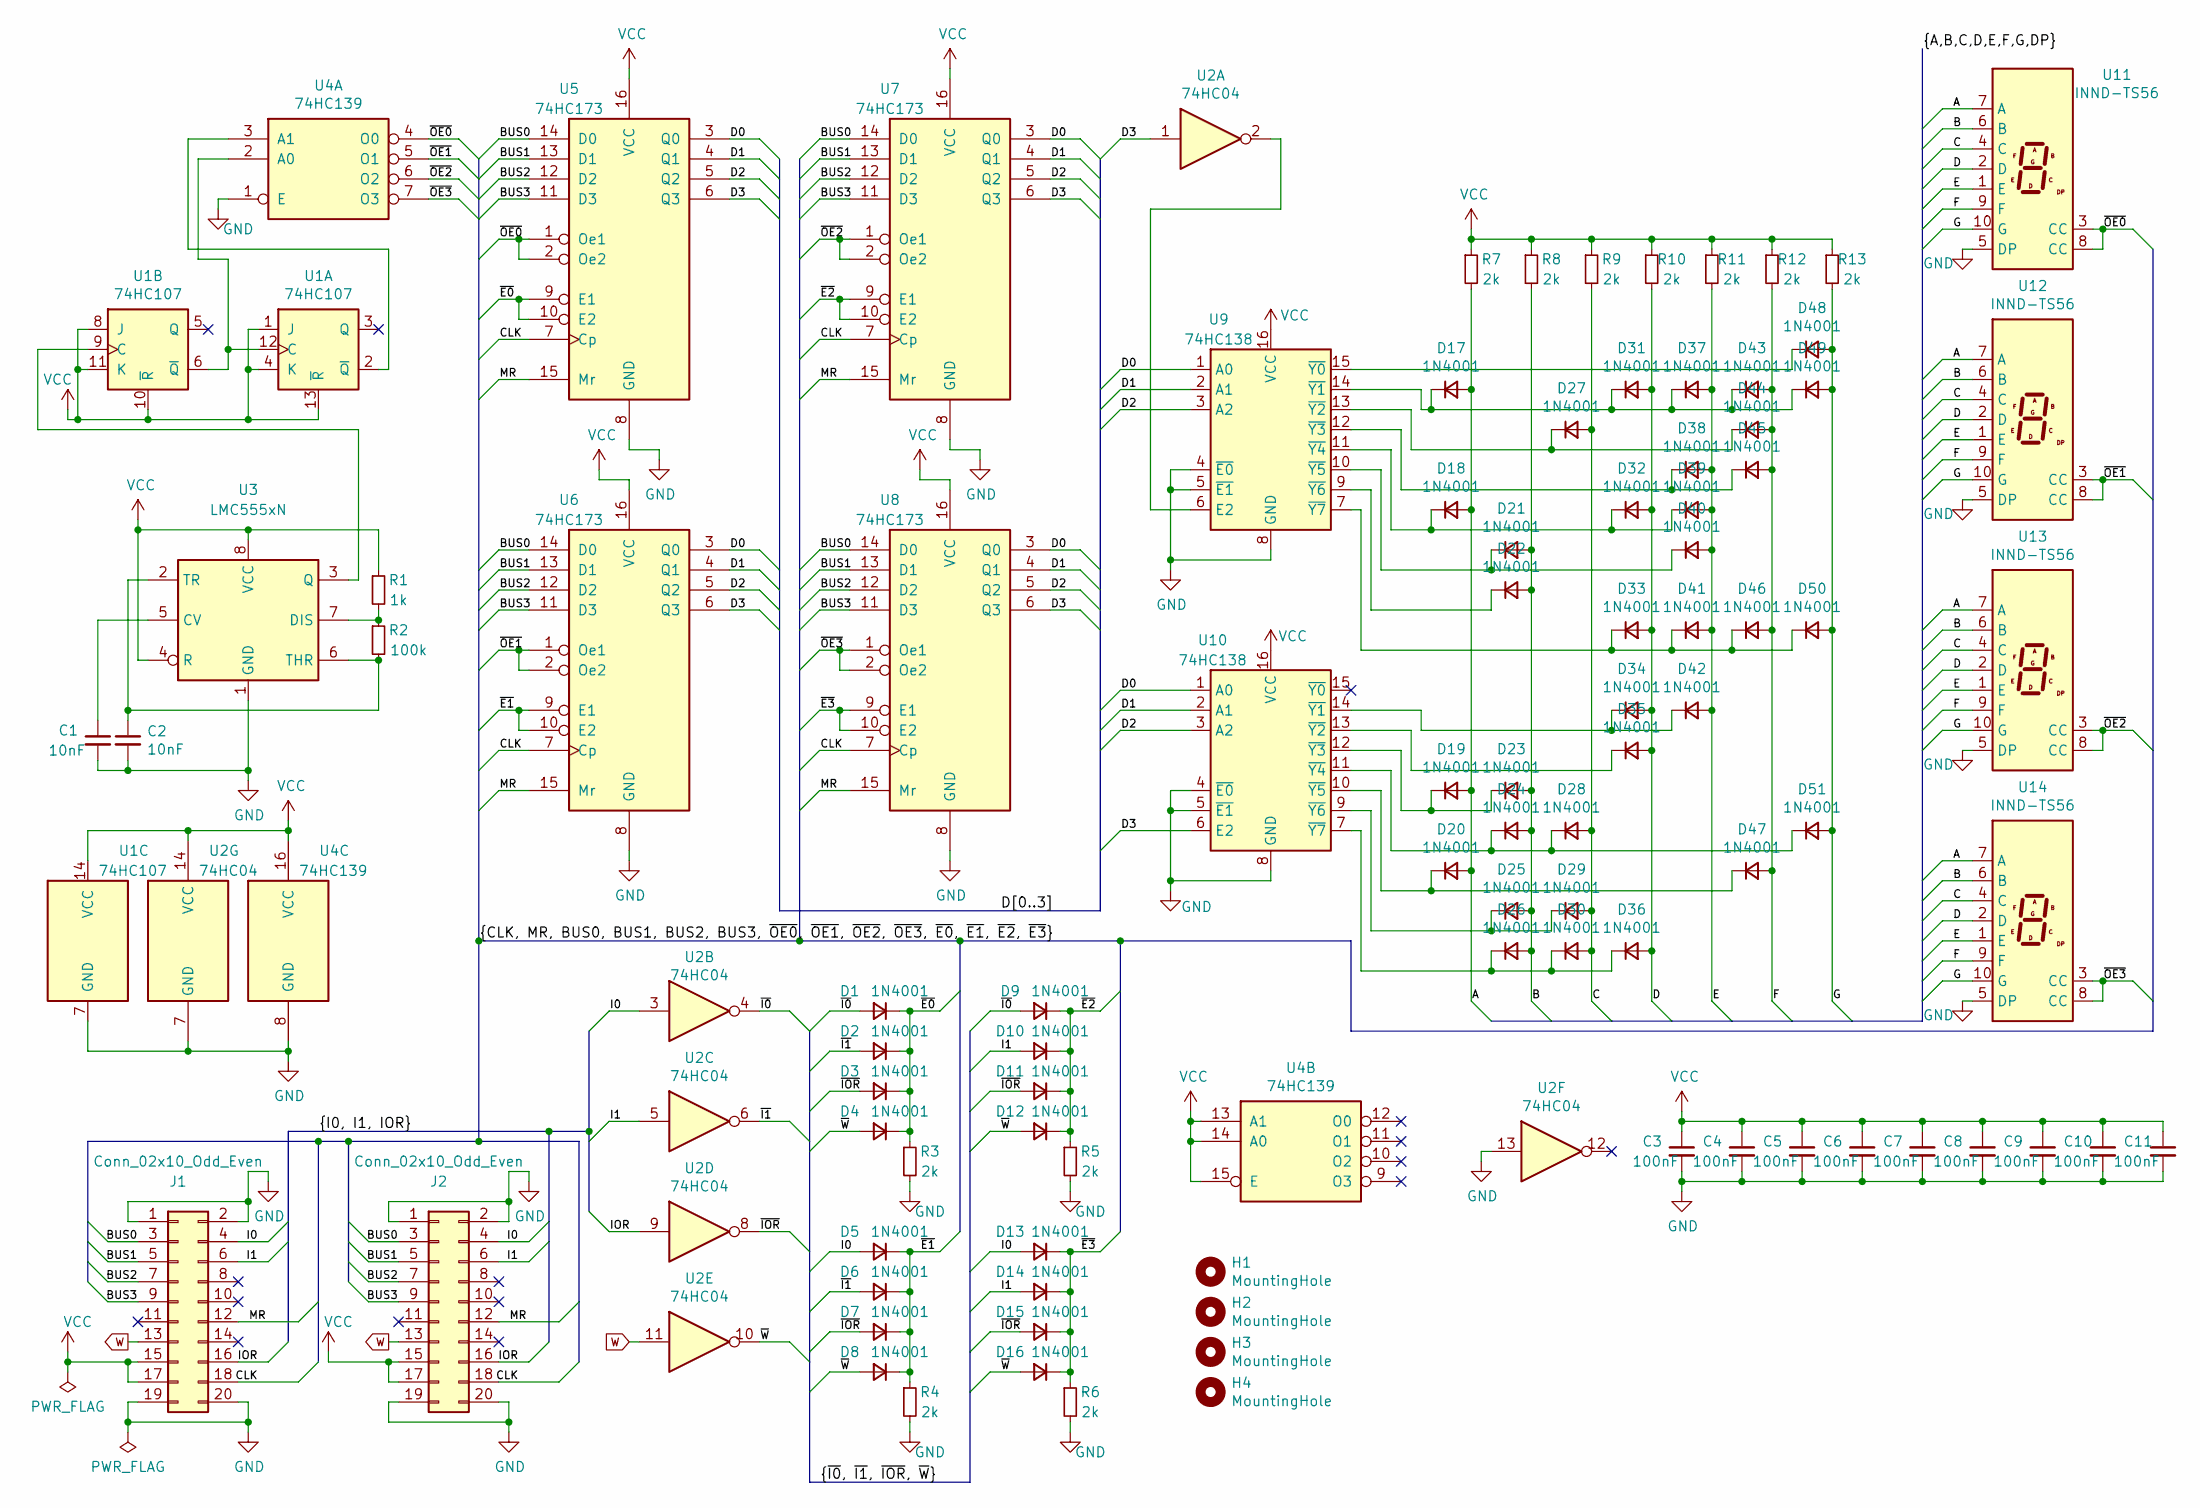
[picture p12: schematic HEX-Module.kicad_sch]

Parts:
C1, C2: 10nF; C_Disc_D4.3mm_W1.9mm_P5.00mm
C3, C4, C5, C6, C7, C8, C9, C10, C11: 100nF; C_Disc_D4.3mm_W1.9mm_P5.00mm
D1, D2, D3, D4, D5, D6, D7, D8, D9, D10, D11, D12, D13, D14, D15, D16, D17, D18, D19, D20, D21, D22, D23, D24, D25, D26, D27, D28, D29, D30, D31, D32, D33, D34, D35, D36, D37, D38, D39, D40, D41, D42, D43, D44, D45, D46, D47, D48, D49, D50, D51: 1N4001; D_DO-41_SOD81_P10.16mm_Horizontal
H1, H2, H3, H4: MountingHole; MountingHole_3.2mm_M3
J1: Conn_02x10_Odd_Even; PinSocket_2x10_P2.54mm_Horizontal
J2: Conn_02x10_Odd_Even; IDC-Header_2x10_P2.54mm_Horizontal
R1: 1k; R_Axial_DIN0207_L6.3mm_D2.5mm_P10.16mm_Horizontal
R2: 100k; R_Axial_DIN0207_L6.3mm_D2.5mm_P10.16mm_Horizontal
R3, R4, R5, R6, R7, R8, R9, R10, R11, R12, R13: 2k; R_Axial_DIN0207_L6.3mm_D2.5mm_P10.16mm_Horizontal
U1: 74HC107; DIP-14_W7.62mm
U2: 74HC04; DIP-14_W7.62mm
U3: LMC555xN; DIP-8_W7.62mm
U4: 74HC139; DIP-16_W7.62mm
U5, U6, U7, U8: 74HC173; DIP-16_W7.62mm
U9, U10: 74HC138; DIP-16_W7.62mm
U11, U12, U13, U14: INND-TS56

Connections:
/A: D17.2 (A), D18.2 (A), D19.2 (A), D20.2 (A), R7.2, U11.7 (A), U12.7 (A), U13.7 (A), U14.7 (A)
/B: D21.2 (A), D22.2 (A), D23.2 (A), D24.2 (A), D25.2 (A), D26.2 (A), R8.2, U11.6 (B), U12.6 (B), U13.6 (B), U14.6 (B)
/BUS0: J1.3, J2.3, U5.14 (D0), U6.14 (D0), U7.14 (D0), U8.14 (D0)
/BUS1: J1.5, J2.5, U5.13 (D1), U6.13 (D1), U7.13 (D1), U8.13 (D1)
/BUS2: J1.7, J2.7, U5.12 (D2), U6.12 (D2), U7.12 (D2), U8.12 (D2)
/BUS3: J1.9, J2.9, U5.11 (D3), U6.11 (D3), U7.11 (D3), U8.11 (D3)
/C: D27.2 (A), D28.2 (A), D29.2 (A), D30.2 (A), R9.2, U11.4 (C), U12.4 (C), U13.4 (C), U14.4 (C)
/CLK: J1.18, J2.18, U5.7 (Cp), U6.7 (Cp), U7.7 (Cp), U8.7 (Cp)
/D: D31.2 (A), D32.2 (A), D33.2 (A), D34.2 (A), D35.2 (A), D36.2 (A), R10.2, U11.2 (D), U12.2 (D), U13.2 (D), U14.2 (D)
/D0: U5.3 (Q0), U6.3 (Q0), U7.3 (Q0), U8.3 (Q0), U9.1 (A0), U10.1 (A0)
/D1: U5.4 (Q1), U6.4 (Q1), U7.4 (Q1), U8.4 (Q1), U9.2 (A1), U10.2 (A1)
/D2: U5.5 (Q2), U6.5 (Q2), U7.5 (Q2), U8.5 (Q2), U9.3 (A2), U10.3 (A2)
/D3: U2.1, U5.6 (Q3), U6.6 (Q3), U7.6 (Q3), U8.6 (Q3), U10.6 (E2)
/E: D37.2 (A), D38.2 (A), D39.2 (A), D40.2 (A), D41.2 (A), D42.2 (A), R11.2, U11.1 (E), U12.1 (E), U13.1 (E), U14.1 (E)
/F: D43.2 (A), D44.2 (A), D45.2 (A), D46.2 (A), D47.2 (A), R12.2, U11.9 (F), U12.9 (F), U13.9 (F), U14.9 (F)
/G: D48.2 (A), D49.2 (A), D50.2 (A), D51.2 (A), R13.2, U11.10 (G), U12.10 (G), U13.10 (G), U14.10 (G)
/I0: D5.2 (A), D13.2 (A), J1.4, J2.4, U2.3
/I1: D10.2 (A), D14.2 (A), J1.6, J2.6, U2.5
/IOR: J1.16, J2.16, U2.9
/MR: J1.12, J2.12, U5.15 (Mr), U6.15 (Mr), U7.15 (Mr), U8.15 (Mr)
/~E0: D1.1 (K), D2.1 (K), D3.1 (K), D4.1 (K), R3.1, U5.9 (E1), U5.10 (E2)
/~E1: D5.1 (K), D6.1 (K), D7.1 (K), D8.1 (K), R4.1, U6.9 (E1), U6.10 (E2)
/~E2: D9.1 (K), D10.1 (K), D11.1 (K), D12.1 (K), R5.1, U7.9 (E1), U7.10 (E2)
/~E3: D13.1 (K), D14.1 (K), D15.1 (K), D16.1 (K), R6.1, U8.9 (E1), U8.10 (E2)
/~I0: D1.2 (A), D9.2 (A), U2.4
/~I1: D2.2 (A), D6.2 (A), U2.6
/~IOR: D3.2 (A), D7.2 (A), D11.2 (A), D15.2 (A), U2.8
/~OE0: U4.4 (O0), U5.1 (Oe1), U5.2 (Oe2), U11.3 (CC), U11.8 (CC)
/~OE1: U4.5 (O1), U6.1 (Oe1), U6.2 (Oe2), U12.3 (CC), U12.8 (CC)
/~OE2: U4.6 (O2), U7.1 (Oe1), U7.2 (Oe2), U13.3 (CC), U13.8 (CC)
/~OE3: U4.7 (O3), U8.1 (Oe1), U8.2 (Oe2), U14.3 (CC), U14.8 (CC)
/~W: D4.2 (A), D8.2 (A), D12.2 (A), D16.2 (A), U2.10
GND: C1.2, C2.2, C3.2, C4.2, C5.2, C6.2, C7.2, C8.2, C9.2, C10.2, C11.2, J1.1, J1.2, J1.19, J1.20, J2.1, J2.2, J2.19, J2.20, R3.2, R4.2, R5.2, R6.2, U1.7 (GND), U2.7 (GND), U2.13, U3.1 (GND), U4.1 (E), U4.8 (GND), U5.8 (GND), U6.8 (GND), U7.8 (GND), U8.8 (GND), U9.4 (~E0), U9.5 (~E1), U9.8 (GND), U10.4 (~E0), U10.5 (~E1), U10.8 (GND), U11.5 (DP), U12.5 (DP), U13.5 (DP), U14.5 (DP)
unnamed: D17.1 (K), D31.1 (K), D37.1 (K), D43.1 (K), D49.1 (K), U9.14 (~Y1)
unnamed: D18.1 (K), D32.1 (K), D39.1 (K), U9.11 (~Y4)
unnamed: D19.1 (K), D23.1 (K), U10.12 (~Y3)
unnamed: D20.1 (K), D47.1 (K), U10.10 (~Y5)
unnamed: D21.1 (K), D40.1 (K), U9.10 (~Y5)
unnamed: D22.1 (K), U9.9 (~Y6)
unnamed: D24.1 (K), D28.1 (K), D51.1 (K), U10.11 (~Y4)
unnamed: D25.1 (K), D29.1 (K), U10.9 (~Y6)
unnamed: D26.1 (K), D30.1 (K), D36.1 (K), U10.7 (~Y7)
unnamed: D27.1 (K), D44.1 (K), U9.13 (~Y2)
unnamed: D33.1 (K), D41.1 (K), D46.1 (K), D50.1 (K), U9.7 (~Y7)
unnamed: D34.1 (K), D42.1 (K), U10.14 (~Y1)
unnamed: D35.1 (K), U10.13 (~Y2)
unnamed: D38.1 (K), D45.1 (K), U9.12 (~Y3)
unnamed: D48.1 (K), U9.15 (~Y0)
unnamed: U1.6 (~Q), U1.12 (C), U4.2 (A0)
unnamed: U1.2 (~Q), U4.3 (A1)
unnamed: U1.9 (C), U3.3 (Q)
unnamed: C1.1, U3.5 (CV)
unnamed: R1.2, R2.1, U3.7 (DIS)
unnamed: C2.1, R2.2, U3.2 (TR), U3.6 (THR)
unnamed: U2.2, U9.6 (E2)
VCC: C3.1, C4.1, C5.1, C6.1, C7.1, C8.1, C9.1, C10.1, C11.1, J1.15, J1.17, J2.15, J2.17, R1.1, R7.1, R8.1, R9.1, R10.1, R11.1, R12.1, R13.1, U1.1 (J), U1.4 (K), U1.8 (J), U1.10 (~R), U1.11 (K), U1.13 (~R), U1.14 (VCC), U2.14 (VCC), U3.4 (R), U3.8 (VCC), U4.13 (A1), U4.14 (A0), U4.15 (E), U4.16 (VCC), U5.16 (VCC), U6.16 (VCC), U7.16 (VCC), U8.16 (VCC), U9.16 (VCC), U10.16 (VCC)
W: J1.13, J2.13, U2.11

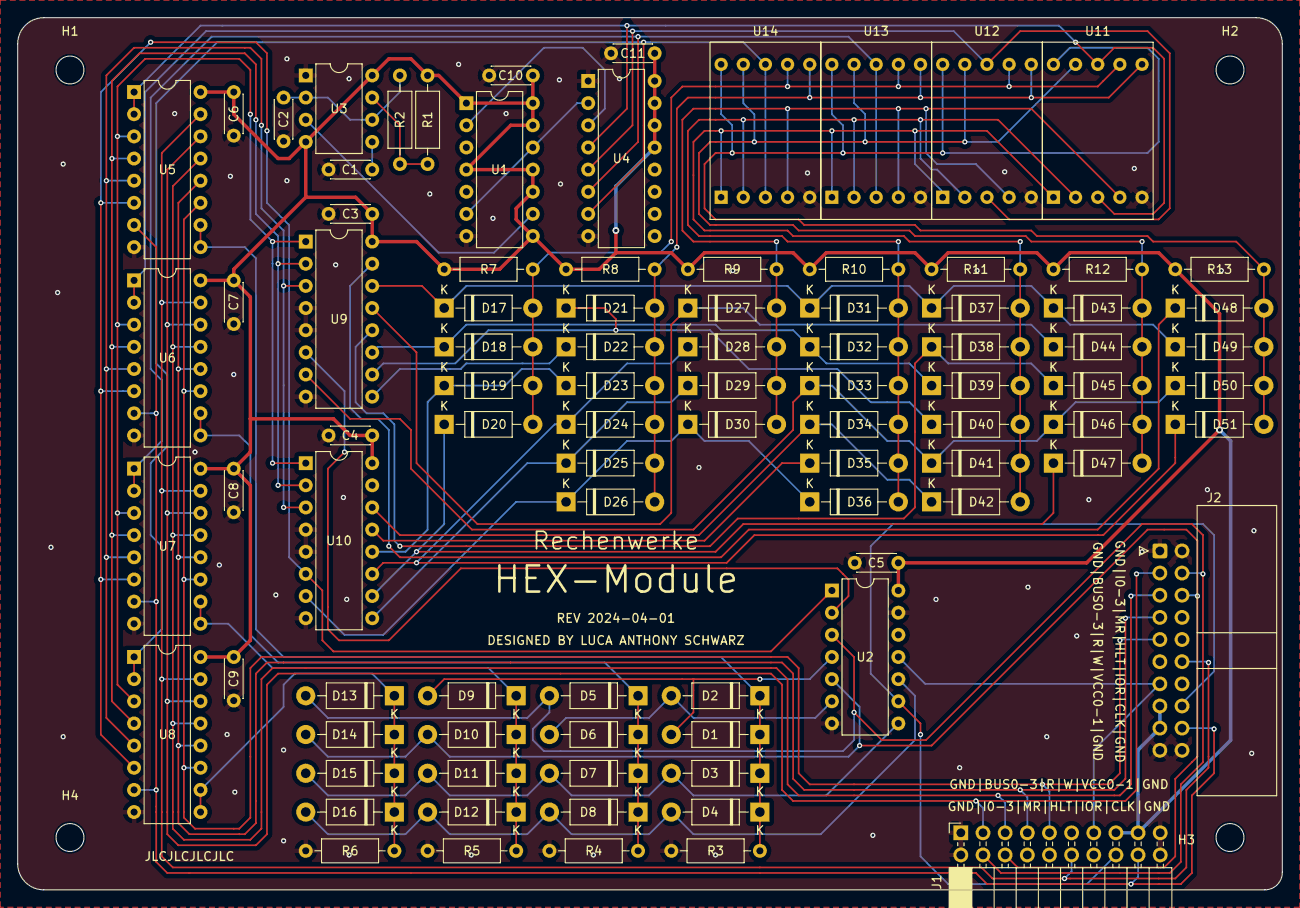
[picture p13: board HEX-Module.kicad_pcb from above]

Board: 2 copper layers, 145.0 x 100.0 mm, 95 parts (0 on the bottom side), 57 nets.

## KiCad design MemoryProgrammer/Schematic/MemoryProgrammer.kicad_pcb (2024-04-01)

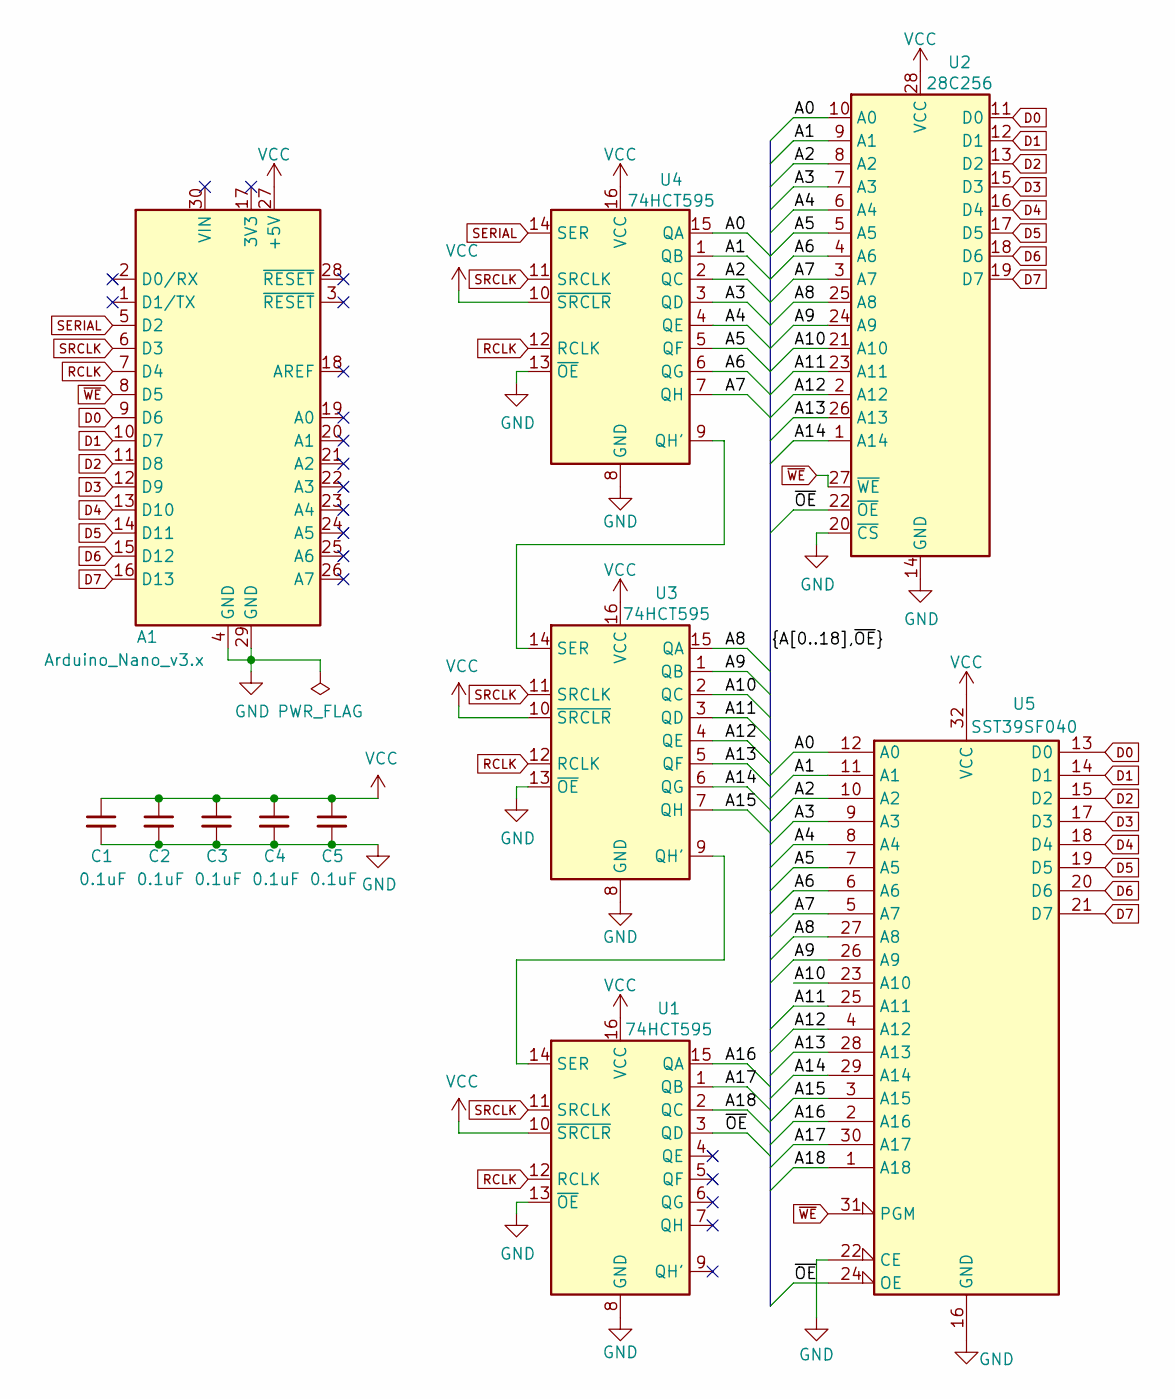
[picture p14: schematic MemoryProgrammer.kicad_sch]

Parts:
A1: Arduino_Nano_v3.x; Arduino_Nano
C1, C2, C3, C4, C5: 0.1uF; C_Disc_D4.3mm_W1.9mm_P5.00mm
U1, U3, U4: 74HCT595; DIP-16_W7.62mm
U2: 28C256; DIP-28_W15.24mm_Socket
U5: SST39SF040; DIP-32_W15.24mm_Socket

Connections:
/A0: U2.10 (A0), U4.15 (QA), U5.12 (A0)
/A1: U2.9 (A1), U4.1 (QB), U5.11 (A1)
/A2: U2.8 (A2), U4.2 (QC), U5.10 (A2)
/A3: U2.7 (A3), U4.3 (QD), U5.9 (A3)
/A4: U2.6 (A4), U4.4 (QE), U5.8 (A4)
/A5: U2.5 (A5), U4.5 (QF), U5.7 (A5)
/A6: U2.4 (A6), U4.6 (QG), U5.6 (A6)
/A7: U2.3 (A7), U4.7 (QH), U5.5 (A7)
/A8: U2.25 (A8), U3.15 (QA), U5.27 (A8)
/A9: U2.24 (A9), U3.1 (QB), U5.26 (A9)
/A10: U2.21 (A10), U3.2 (QC), U5.23 (A10)
/A11: U2.23 (A11), U3.3 (QD), U5.25 (A11)
/A12: U2.2 (A12), U3.4 (QE), U5.4 (A12)
/A13: U2.26 (A13), U3.5 (QF), U5.28 (A13)
/A14: U2.1 (A14), U3.6 (QG), U5.29 (A14)
/A15: U3.7 (QH), U5.3 (A15)
/A16: U1.15 (QA), U5.2 (A16)
/A17: U1.1 (QB), U5.30 (A17)
/A18: U1.2 (QC), U5.1 (A18)
/~OE: U1.3 (QD), U2.22 (~OE), U5.24 (OE)
D0: A1.9 (D6), U2.11 (D0), U5.13 (D0)
D1: A1.10 (D7), U2.12 (D1), U5.14 (D1)
D2: A1.11 (D8), U2.13 (D2), U5.15 (D2)
D3: A1.12 (D9), U2.15 (D3), U5.17 (D3)
D4: A1.13 (D10), U2.16 (D4), U5.18 (D4)
D5: A1.14 (D11), U2.17 (D5), U5.19 (D5)
D6: A1.15 (D12), U2.18 (D6), U5.20 (D6)
D7: A1.16 (D13), U2.19 (D7), U5.21 (D7)
GND: A1.4 (GND), A1.29 (GND), C1.2, C2.2, C3.2, C4.2, C5.2, U1.8 (GND), U1.13 (~OE), U2.14 (GND), U2.20 (~CS), U3.8 (GND), U3.13 (~OE), U4.8 (GND), U4.13 (~OE), U5.16 (GND), U5.22 (CE)
unnamed: U1.14 (SER), U3.9 (QH')
unnamed: U3.14 (SER), U4.9 (QH')
RCLK: A1.7 (D4), U1.12 (RCLK), U3.12 (RCLK), U4.12 (RCLK)
SERIAL: A1.5 (D2), U4.14 (SER)
SRCLK: A1.6 (D3), U1.11 (SRCLK), U3.11 (SRCLK), U4.11 (SRCLK)
VCC: A1.27 (+5V), C1.1, C2.1, C3.1, C4.1, C5.1, U1.10 (~SRCLR), U1.16 (VCC), U2.28 (VCC), U3.10 (~SRCLR), U3.16 (VCC), U4.10 (~SRCLR), U4.16 (VCC), U5.32 (VCC)
~WE: A1.8 (D5), U2.27 (~WE), U5.31 (PGM)

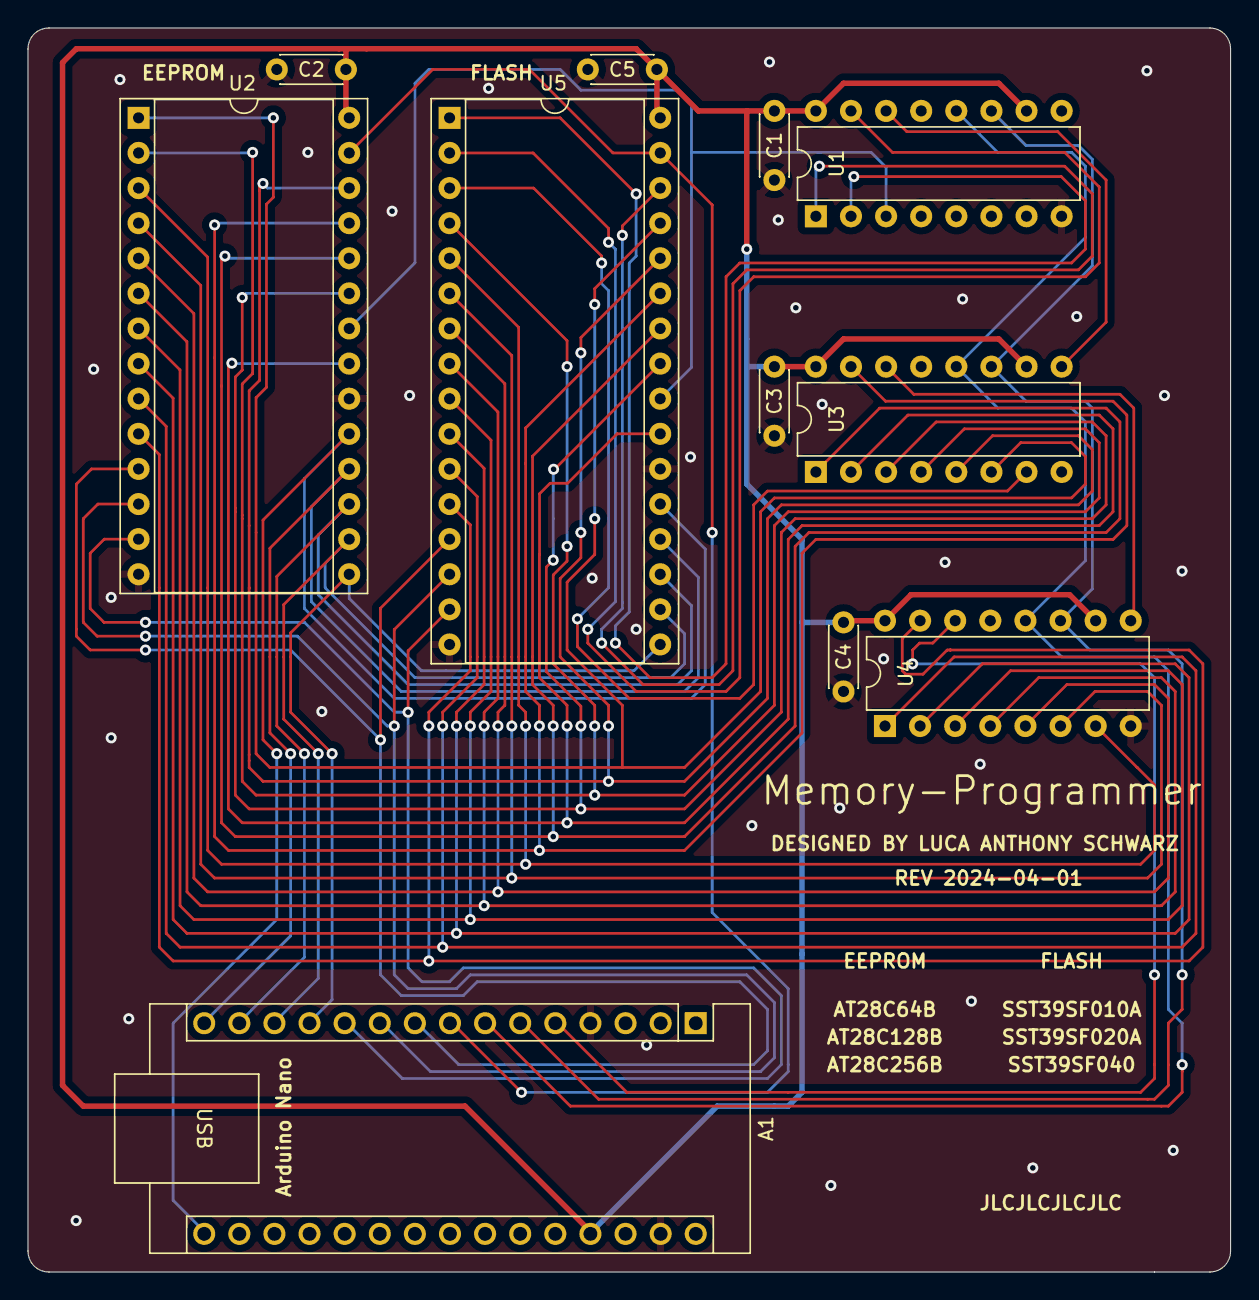
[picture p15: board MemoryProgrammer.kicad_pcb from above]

Board: 2 copper layers, 87.0 x 90.0 mm, 11 parts (0 on the bottom side), 36 nets.

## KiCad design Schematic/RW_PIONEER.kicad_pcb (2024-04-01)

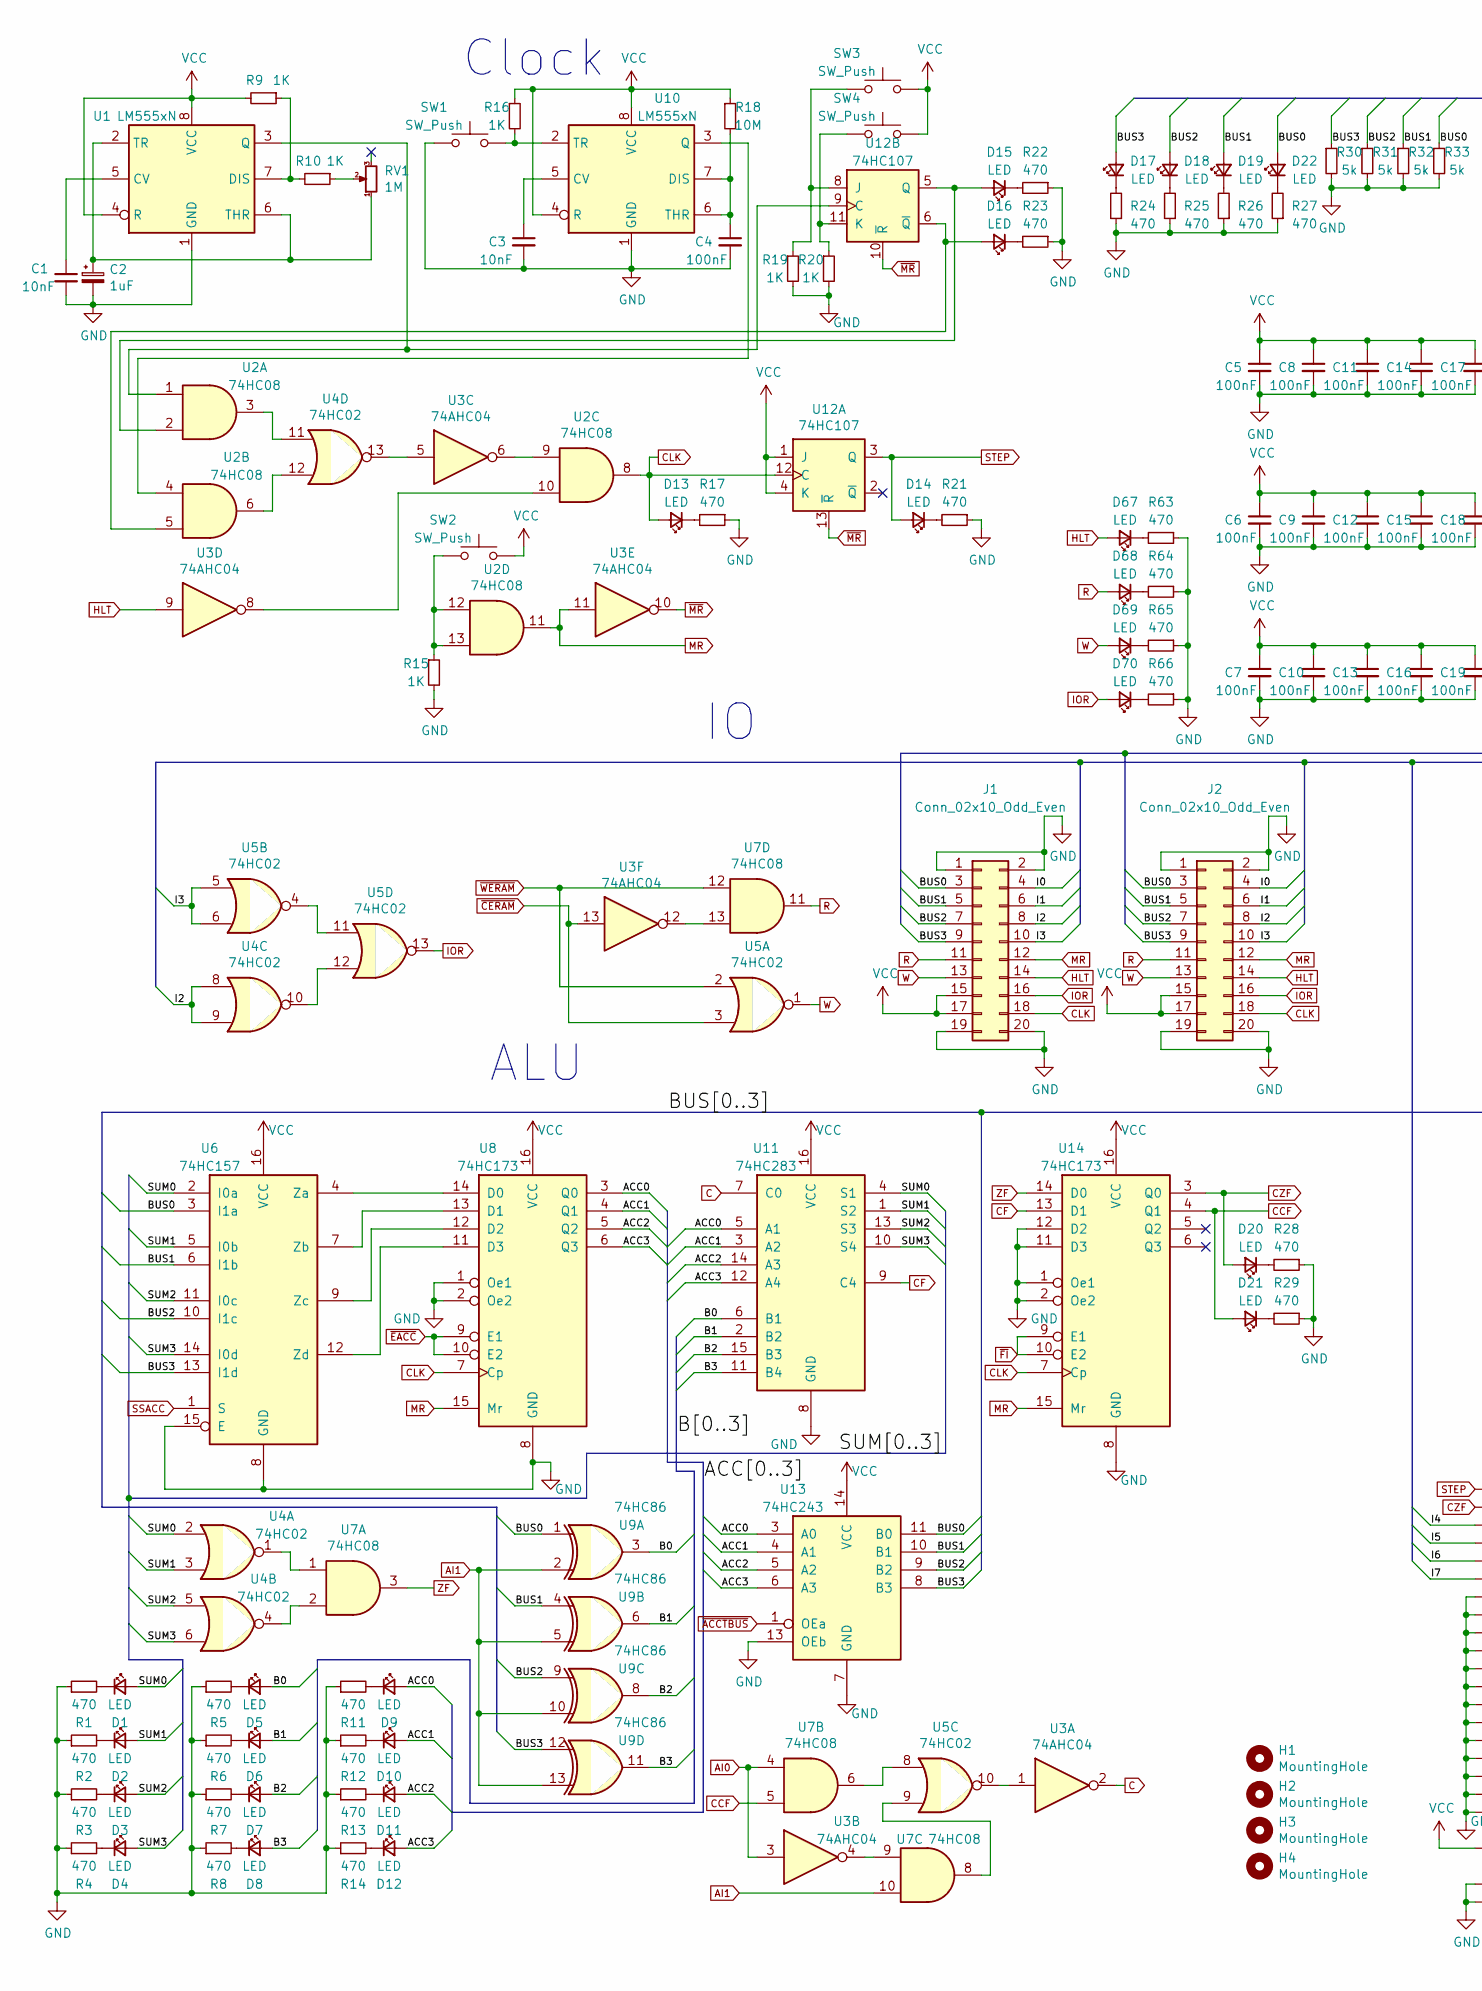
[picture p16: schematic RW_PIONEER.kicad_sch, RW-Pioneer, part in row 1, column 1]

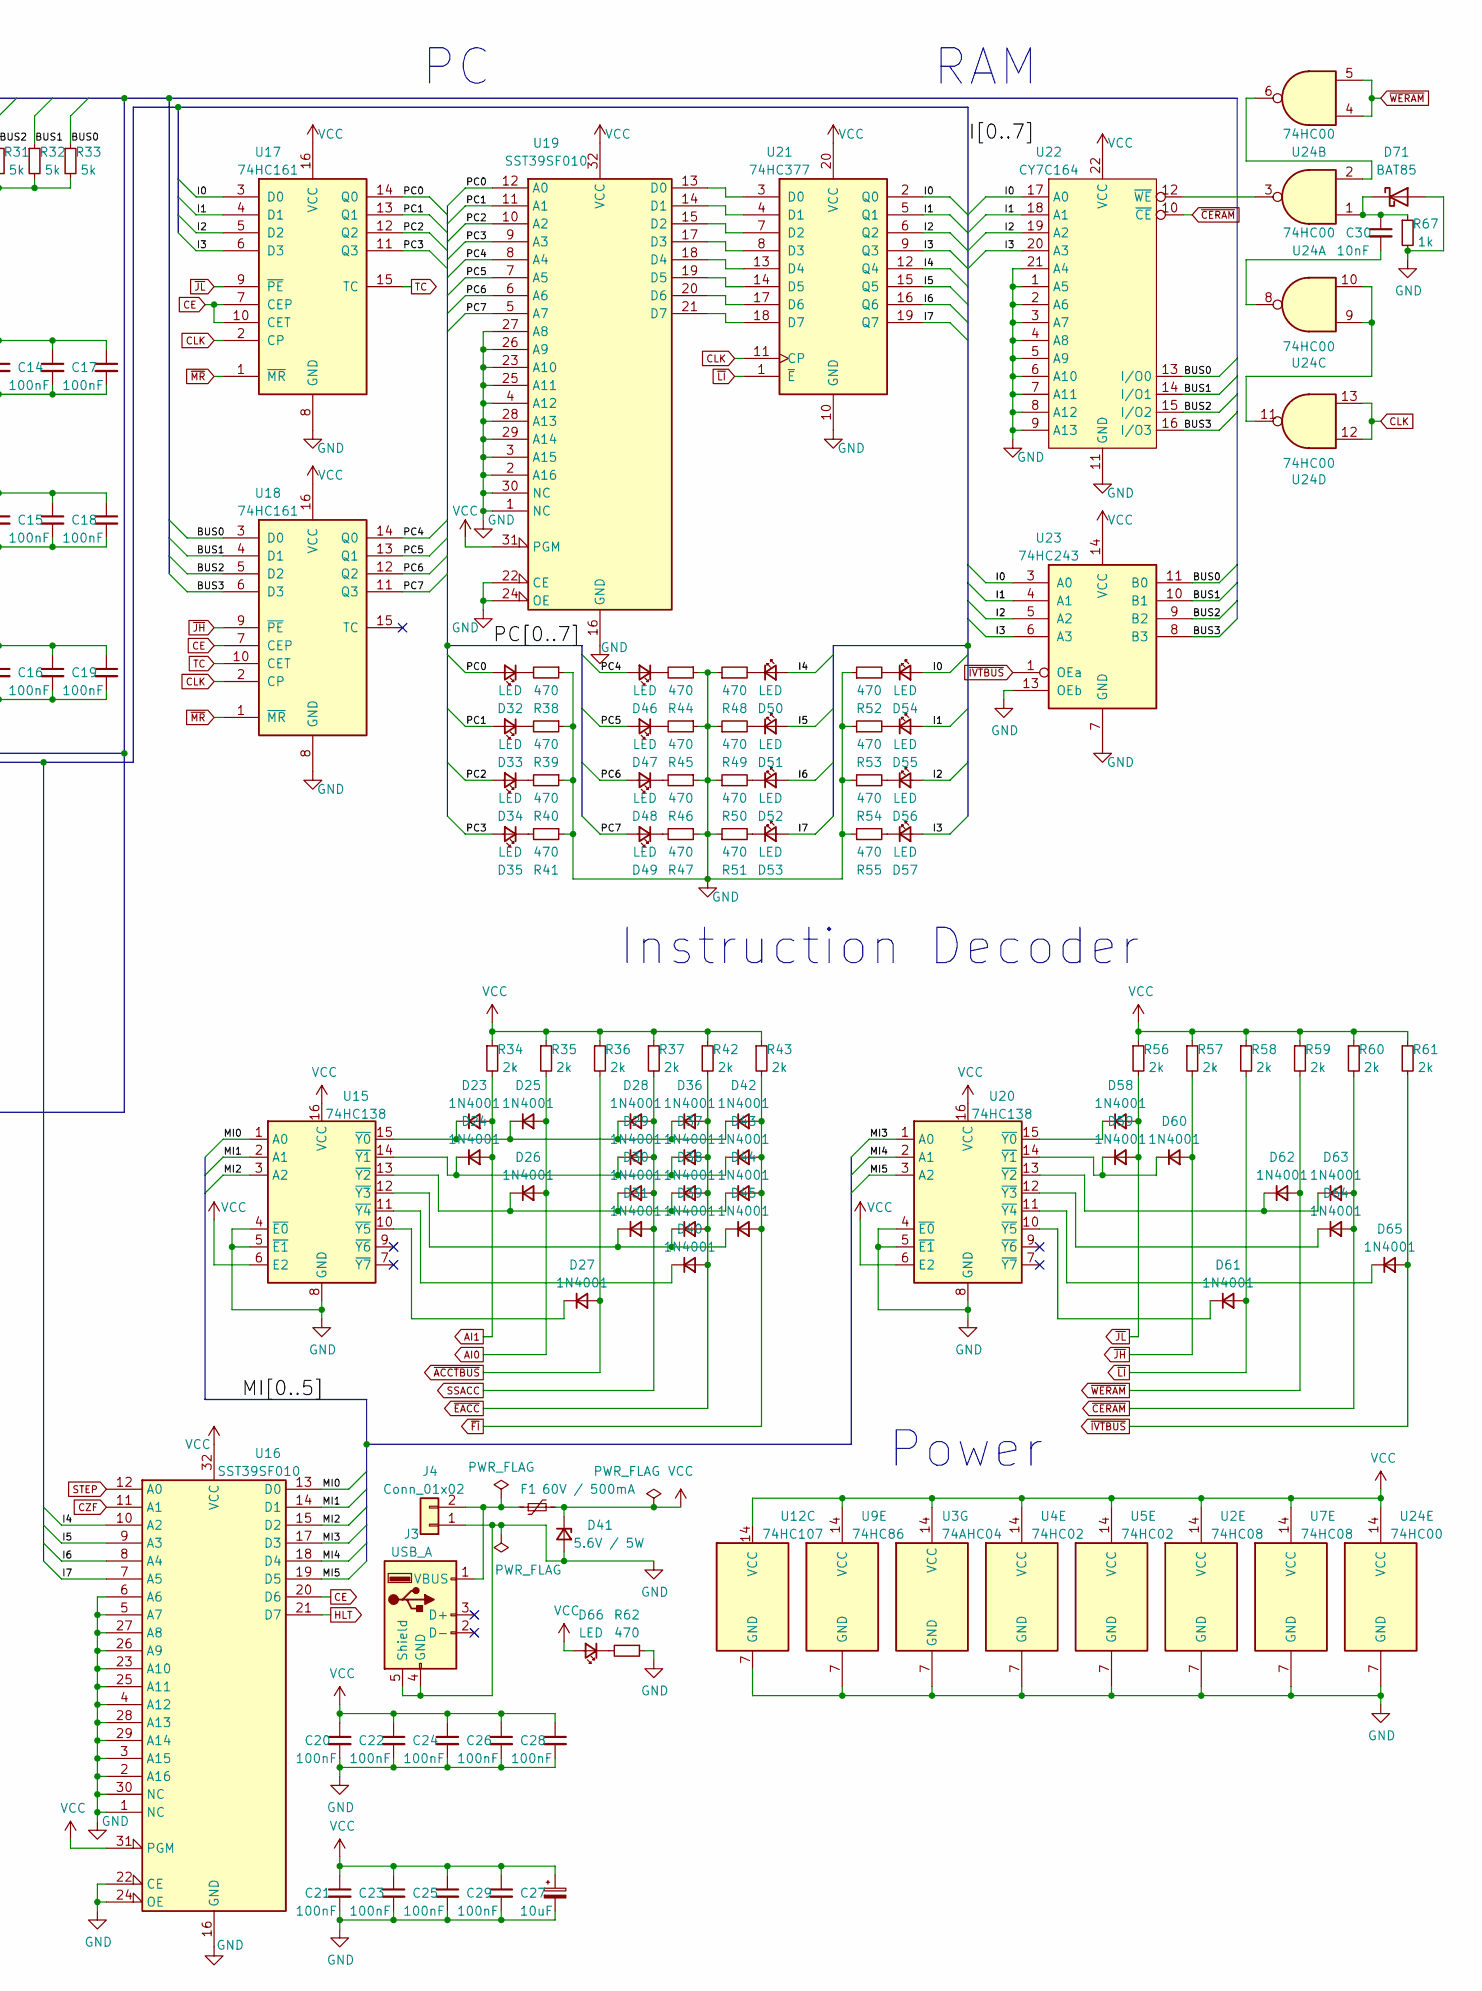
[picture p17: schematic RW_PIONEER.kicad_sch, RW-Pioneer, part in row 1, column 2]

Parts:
C1, C3, C30: 10nF; C_Disc_D4.3mm_W1.9mm_P5.00mm
C2: 1uF; CP_Radial_D5.0mm_P2.50mm
C4, C5, C6, C7, C8, C9, C10, C11, C12, C13, C14, C15, C16, C17, C18, C19, C20, C21, C22, C23, C24, C25, C26, C28, C29: 100nF; C_Disc_D4.3mm_W1.9mm_P5.00mm
C27: 10uF; CP_Radial_D5.0mm_P2.50mm
D1, D2, D3, D4, D5, D6, D7, D8, D9, D10, D11, D12, D13, D14, D15, D16, D17, D18, D19, D20, D21, D22, D32, D33, D34, D35, D46, D47, D48, D49, D50, D51, D52, D53, D54, D55, D56, D57, D66, D67, D68, D69, D70: LED; LED_D5.0mm_Clear
D23, D24, D25, D26, D27, D28, D29, D30, D31, D36, D37, D38, D39, D40, D42, D43, D44, D45, D58, D59, D60, D61, D62, D63, D64, D65: 1N4001; D_DO-41_SOD81_P10.16mm_Horizontal
D41: 5.6V / 5W; D_DO-41_SOD81_P12.70mm_Horizontal
D71: BAT85; D_DO-35_SOD27_P7.62mm_Horizontal
F1: 60V / 500mA; R_Axial_DIN0207_L6.3mm_D2.5mm_P5.08mm_Vertical
H1, H2, H3, H4: MountingHole; MountingHole_3.2mm_M3
J1: Conn_02x10_Odd_Even; PinHeader_2x10_P2.54mm_Horizontal
J2: Conn_02x10_Odd_Even; IDC-Header_2x10_P2.54mm_Horizontal
J3: USB_A; USB_A_CONNFLY_DS1095-WNR0
J4: Conn_01x02; JST_XH_B2B-XH-A_1x02_P2.50mm_Vertical
R1, R2, R3, R4, R5, R6, R7, R8, R11, R12, R13, R14, R17, R21, R22, R23, R24, R25, R26, R27, R28, R29, R38, R39, R40, R41, R44, R45, R46, R47, R48, R49, R50, R51, R52, R53, R54, R55, R62, R63, R64, R65, R66: 470; R_Axial_DIN0207_L6.3mm_D2.5mm_P10.16mm_Horizontal
R9, R10, R15, R16, R19, R20: 1K; R_Axial_DIN0207_L6.3mm_D2.5mm_P10.16mm_Horizontal
R18: 10M; R_Axial_DIN0207_L6.3mm_D2.5mm_P10.16mm_Horizontal
R30, R31, R32, R33: 5k; R_Axial_DIN0207_L6.3mm_D2.5mm_P10.16mm_Horizontal
R34, R35, R36, R37, R42, R43, R56, R57, R58, R59, R60, R61: 2k; R_Axial_DIN0207_L6.3mm_D2.5mm_P10.16mm_Horizontal
R67: 1k; R_Axial_DIN0207_L6.3mm_D2.5mm_P10.16mm_Horizontal
RV1: 1M; Potentiometer_Piher_PT-10-H01_Horizontal
SW1, SW2, SW3, SW4: SW_Push; SW_PUSH_6mm
U1, U10: LM555xN; DIP-8_W7.62mm
U2, U7: 74HC08; DIP-14_W7.62mm
U3: 74AHC04; DIP-14_W7.62mm
U4, U5: 74HC02; DIP-14_W7.62mm
U6: 74HC157; DIP-16_W7.62mm
U8, U14: 74HC173; DIP-16_W7.62mm
U9: 74HC86; DIP-14_W7.62mm
U11: 74HC283; DIP-16_W7.62mm
U12: 74HC107; DIP-14_W7.62mm
U13, U23: 74HC243; DIP-14_W7.62mm
U15, U20: 74HC138; DIP-16_W7.62mm
U16, U19: SST39SF010; DIP-32_W15.24mm_Socket
U17, U18: 74HC161; DIP-16_W7.62mm
U21: 74HC377; DIP-20_W7.62mm
U22: CY7C164; DIP-22_W7.62mm
U24: 74HC00; DIP-14_W7.62mm

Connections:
/ACC0: D9.2 (A), U8.3 (Q0), U11.5 (A1), U13.3 (A0)
/ACC1: D10.2 (A), U8.4 (Q1), U11.3 (A2), U13.4 (A1)
/ACC2: D11.2 (A), U8.5 (Q2), U11.14 (A3), U13.5 (A2)
/ACC3: D12.2 (A), U8.6 (Q3), U11.12 (A4), U13.6 (A3)
/B0: D5.2 (A), U9.3, U11.6 (B1)
/B1: D6.2 (A), U9.6, U11.2 (B2)
/B2: D7.2 (A), U9.8, U11.15 (B3)
/B3: D8.2 (A), U9.11, U11.11 (B4)
/BUS0: D22.2 (A), J1.3, J2.3, R33.1, U6.3 (I1a), U9.1, U13.11 (B0), U18.3 (D0), U22.13 (I/O0), U23.11 (B0)
/BUS1: D19.2 (A), J1.5, J2.5, R32.1, U6.6 (I1b), U9.4, U13.10 (B1), U18.4 (D1), U22.14 (I/O1), U23.10 (B1)
/BUS2: D18.2 (A), J1.7, J2.7, R31.1, U6.10 (I1c), U9.9, U13.9 (B2), U18.5 (D2), U22.15 (I/O2), U23.9 (B2)
/BUS3: D17.2 (A), J1.9, J2.9, R30.1, U6.13 (I1d), U9.12, U13.8 (B3), U18.6 (D3), U22.16 (I/O3), U23.8 (B3)
/I0: D54.2 (A), J1.4, J2.4, U17.3 (D0), U21.2 (Q0), U22.17 (A0), U23.3 (A0)
/I1: D55.2 (A), J1.6, J2.6, U17.4 (D1), U21.5 (Q1), U22.18 (A1), U23.4 (A1)
/I2: D56.2 (A), J1.8, J2.8, U4.8, U4.9, U17.5 (D2), U21.6 (Q2), U22.19 (A2), U23.5 (A2)
/I3: D57.2 (A), J1.10, J2.10, U5.5, U5.6, U17.6 (D3), U21.9 (Q3), U22.20 (A3), U23.6 (A3)
/I4: D50.2 (A), U16.10 (A2), U21.12 (Q4)
/I5: D51.2 (A), U16.9 (A3), U21.15 (Q5)
/I6: D52.2 (A), U16.8 (A4), U21.16 (Q6)
/I7: D53.2 (A), U16.7 (A5), U21.19 (Q7)
/MI0: U15.1 (A0), U16.13 (D0)
/MI1: U15.2 (A1), U16.14 (D1)
/MI2: U15.3 (A2), U16.15 (D2)
/MI3: U16.17 (D3), U20.1 (A0)
/MI4: U16.18 (D4), U20.2 (A1)
/MI5: U16.19 (D5), U20.3 (A2)
/PC0: D32.2 (A), U17.14 (Q0), U19.12 (A0)
/PC1: D33.2 (A), U17.13 (Q1), U19.11 (A1)
/PC2: D34.2 (A), U17.12 (Q2), U19.10 (A2)
/PC3: D35.2 (A), U17.11 (Q3), U19.9 (A3)
/PC4: D46.2 (A), U18.14 (Q0), U19.8 (A4)
/PC5: D47.2 (A), U18.13 (Q1), U19.7 (A5)
/PC6: D48.2 (A), U18.12 (Q2), U19.6 (A6)
/PC7: D49.2 (A), U18.11 (Q3), U19.5 (A7)
/SUM0: D1.2 (A), U4.2, U6.2 (I0a), U11.4 (S1)
/SUM1: D2.2 (A), U4.3, U6.5 (I0b), U11.1 (S2)
/SUM2: D3.2 (A), U4.5, U6.11 (I0c), U11.13 (S3)
/SUM3: D4.2 (A), U4.6, U6.14 (I0d), U11.10 (S4)
AI0: D25.2 (A), D26.2 (A), R35.2, U3.3, U7.4
AI1: D23.2 (A), D24.2 (A), R34.2, U7.10, U9.2, U9.5, U9.10, U9.13
C: U3.2, U11.7 (C0)
CCF: D21.2 (A), U7.5, U14.4 (Q1)
CE: U16.20 (D6), U17.7 (CEP), U17.10 (CET), U18.7 (CEP)
CF: U11.9 (C4), U14.13 (D1)
CLK: D13.2 (A), J1.18, J2.18, U2.8, U8.7 (Cp), U12.12 (C), U14.7 (Cp), U17.2 (CP), U18.2 (CP), U21.11 (CP), U24.12, U24.13
CZF: D20.2 (A), U14.3 (Q0), U16.11 (A1)
GND: C1.2, C2.2, C3.2, C4.2, C5.2, C6.2, C7.2, C8.2, C9.2, C10.2, C11.2, C12.2, C13.2, C14.2, C15.2, C16.2, C17.2, C18.2, C19.2, C20.2, C21.2, C22.2, C23.2, C24.2, C25.2, C26.2, C27.2, C28.2, C29.2, D41.2 (A), D71.2 (A), J1.1, J1.2, J1.19, J1.20, J2.1, J2.2, J2.19, J2.20, J3.4 (GND), J3.5 (Shield), J4.1, R1.1, R2.1, R3.1, R4.1, R5.1, R6.1, R7.1, R8.1, R11.1, R12.1, R13.1, R14.1, R15.2, R17.1, R19.2, R20.2, R21.1, R22.1, R23.1, R24.1, R25.1, R26.1, R27.1, R28.1, R29.1, R30.2, R31.2, R32.2, R33.2, R38.1, R39.1, R40.1, R41.1, R44.1, R45.1, R46.1, R47.1, R48.1, R49.1, R50.1, R51.1, R52.1, R53.1, R54.1, R55.1, R62.1, R63.1, R64.1, R65.1, R66.1, R67.2, SW1.1, U1.1 (GND), U2.7 (GND), U3.7 (GND), U4.7 (GND), U5.7 (GND), U6.8 (GND), U6.15 (E), U7.7 (GND), U8.1 (Oe1), U8.2 (Oe2), U8.8 (GND), U9.7 (GND), U10.1 (GND), U11.8 (GND), U12.7 (GND), U13.7 (GND), U13.13 (OEb), U14.1 (Oe1), U14.2 (Oe2), U14.8 (GND), U14.11 (D3), U14.12 (D2), U15.4 (~E0), U15.5 (~E1), U15.8 (GND), U16.1 (NC), U16.2 (A16), U16.3 (A15), U16.4 (A12), U16.5 (A7), U16.6 (A6), U16.16 (GND), U16.22 (CE), U16.23 (A10), U16.24 (OE), U16.25 (A11), U16.26 (A9), U16.27 (A8), U16.28 (A13), U16.29 (A14), U16.30 (NC), U17.8 (GND), U18.8 (GND), U19.1 (NC), U19.2 (A16), U19.3 (A15), U19.4 (A12), U19.16 (GND), U19.22 (CE), U19.23 (A10), U19.24 (OE), U19.25 (A11), U19.26 (A9), U19.27 (A8), U19.28 (A13), U19.29 (A14), U19.30 (NC), U20.4 (~E0), U20.5 (~E1), U20.8 (GND), U21.10 (GND), U22.1 (A5), U22.2 (A6), U22.3 (A7), U22.4 (A8), U22.5 (A9), U22.6 (A10), U22.7 (A11), U22.8 (A12), U22.9 (A13), U22.11 (GND), U22.21 (A4), U23.7 (GND), U23.13 (OEb), U24.7 (GND)
HLT: D67.2 (A), J1.14, J2.14, U3.9, U16.21 (D7)
IOR: D70.2 (A), J1.16, J2.16, U5.13
MR: J1.12, J2.12, U2.11, U3.11, U8.15 (Mr), U14.15 (Mr)
unnamed: C30.2, U24.8
unnamed: D1.1 (K), R1.2
unnamed: D2.1 (K), R2.2
unnamed: D3.1 (K), R3.2
unnamed: D4.1 (K), R4.2
unnamed: D5.1 (K), R5.2
unnamed: D6.1 (K), R6.2
unnamed: D7.1 (K), R7.2
unnamed: D8.1 (K), R8.2
unnamed: D9.1 (K), R11.2
unnamed: D10.1 (K), R12.2
unnamed: D11.1 (K), R13.2
unnamed: D12.1 (K), R14.2
unnamed: D13.1 (K), R17.2
unnamed: D14.1 (K), R21.2
unnamed: D15.2 (A), U2.2, U12.5 (Q)
unnamed: D15.1 (K), R22.2
unnamed: D16.2 (A), U2.5, U12.6 (~Q)
unnamed: D16.1 (K), R23.2
unnamed: D17.1 (K), R24.2
unnamed: D18.1 (K), R25.2
unnamed: D19.1 (K), R26.2
unnamed: D20.1 (K), R28.2
unnamed: D21.1 (K), R29.2
unnamed: D22.1 (K), R27.2
unnamed: D23.1 (K), D25.1 (K), D28.1 (K), D36.1 (K), D42.1 (K), U15.15 (~Y0)
unnamed: D24.1 (K), D29.1 (K), D37.1 (K), D43.1 (K), U15.14 (~Y1)
unnamed: D26.1 (K), D30.1 (K), D38.1 (K), D44.1 (K), U15.13 (~Y2)
unnamed: D27.1 (K), U15.10 (~Y5)
unnamed: D31.1 (K), D39.1 (K), D45.1 (K), U15.12 (~Y3)
unnamed: D32.1 (K), R38.2
unnamed: D33.1 (K), R39.2
unnamed: D34.1 (K), R40.2
unnamed: D35.1 (K), R41.2
unnamed: D40.1 (K), U15.11 (~Y4)
unnamed: D46.1 (K), R44.2
unnamed: D47.1 (K), R45.2
unnamed: D48.1 (K), R46.2
unnamed: D49.1 (K), R47.2
unnamed: D50.1 (K), R48.2
unnamed: D51.1 (K), R49.2
unnamed: D52.1 (K), R50.2
unnamed: D53.1 (K), R51.2
unnamed: D54.1 (K), R52.2
unnamed: D55.1 (K), R53.2
unnamed: D56.1 (K), R54.2
unnamed: D57.1 (K), R55.2
unnamed: D58.1 (K), U20.15 (~Y0)
unnamed: D59.1 (K), D60.1 (K), U20.14 (~Y1)
unnamed: D61.1 (K), U20.10 (~Y5)
unnamed: D62.1 (K), D63.1 (K), U20.13 (~Y2)
unnamed: D64.1 (K), U20.12 (~Y3)
unnamed: D65.1 (K), U20.11 (~Y4)
unnamed: D66.1 (K), R62.2
unnamed: D67.1 (K), R63.2
unnamed: D68.1 (K), R64.2
unnamed: D69.1 (K), R65.2
unnamed: D70.1 (K), R66.2
unnamed: C30.1, D71.1 (K), R67.1, U24.1
unnamed: F1.1, J3.1 (VBUS), J4.2
unnamed: R10.1, RV1.2
unnamed: R15.1, SW2.1, U2.12, U2.13
unnamed: C1.1, U1.5 (CV)
unnamed: R9.1, R10.2, U1.7 (DIS)
unnamed: U1.3 (Q), U2.1, U12.9 (C)
unnamed: C2.1, RV1.1, U1.2 (TR), U1.6 (THR)
unnamed: U2.3, U4.11
unnamed: U2.6, U4.12
unnamed: U2.9, U3.6
unnamed: U2.10, U3.8
unnamed: U3.1, U5.10
unnamed: U3.4, U7.9
unnamed: U3.5, U4.13
unnamed: U3.12, U7.13
unnamed: U4.1, U7.1
unnamed: U4.4, U7.2
unnamed: U4.10, U5.12
unnamed: U5.8, U7.6
unnamed: U5.9, U7.8
unnamed: U5.4, U5.11
unnamed: U6.4 (Za), U8.14 (D0)
unnamed: U6.7 (Zb), U8.13 (D1)
unnamed: U6.9 (Zc), U8.12 (D2)
unnamed: U6.12 (Zd), U8.11 (D3)
unnamed: C3.1, U10.5 (CV)
unnamed: C4.1, R18.2, U10.6 (THR), U10.7 (DIS)
unnamed: U2.4, U10.3 (Q)
unnamed: R16.2, SW1.2, U10.2 (TR)
unnamed: R19.1, SW3.1, U12.8 (J)
unnamed: R20.1, SW4.1, U12.11 (K)
unnamed: U19.13 (D0), U21.3 (D0)
unnamed: U19.14 (D1), U21.4 (D1)
unnamed: U19.15 (D2), U21.7 (D2)
unnamed: U19.17 (D3), U21.8 (D3)
unnamed: U19.18 (D4), U21.13 (D4)
unnamed: U19.19 (D5), U21.14 (D5)
unnamed: U19.20 (D6), U21.17 (D6)
unnamed: U19.21 (D7), U21.18 (D7)
unnamed: U22.12 (~WE), U24.3
unnamed: U24.2, U24.6
unnamed: U24.9, U24.10, U24.11
R: D68.2 (A), J1.11, J2.11, U7.11
SSACC: D28.2 (A), D29.2 (A), D30.2 (A), D31.2 (A), R37.2, U6.1 (S)
STEP: D14.2 (A), U12.3 (Q), U16.12 (A0)
TC: U17.15 (TC), U18.10 (CET)
VCC: C5.1, C6.1, C7.1, C8.1, C9.1, C10.1, C11.1, C12.1, C13.1, C14.1, C15.1, C16.1, C17.1, C18.1, C19.1, C20.1, C21.1, C22.1, C23.1, C24.1, C25.1, C26.1, C27.1, C28.1, C29.1, D41.1 (K), D66.2 (A), F1.2, J1.15, J1.17, J2.15, J2.17, R9.2, R16.1, R18.1, R34.1, R35.1, R36.1, R37.1, R42.1, R43.1, R56.1, R57.1, R58.1, R59.1, R60.1, R61.1, SW2.2, SW3.2, SW4.2, U1.4 (R), U1.8 (VCC), U2.14 (VCC), U3.14 (VCC), U4.14 (VCC), U5.14 (VCC), U6.16 (VCC), U7.14 (VCC), U8.16 (VCC), U9.14 (VCC), U10.4 (R), U10.8 (VCC), U11.16 (VCC), U12.1 (J), U12.4 (K), U12.14 (VCC), U13.14 (VCC), U14.16 (VCC), U15.6 (E2), U15.16 (VCC), U16.31 (PGM), U16.32 (VCC), U17.16 (VCC), U18.16 (VCC), U19.31 (PGM), U19.32 (VCC), U20.6 (E2), U20.16 (VCC), U21.20 (VCC), U22.22 (VCC), U23.14 (VCC), U24.14 (VCC)
W: D69.2 (A), J1.13, J2.13, U5.1
ZF: U7.3, U14.14 (D0)
~ACCTBUS: D27.2 (A), R36.2, U13.1 (OEa)
~CERAM: D63.2 (A), D64.2 (A), R60.2, U3.13, U5.3, U22.10 (~CE)
~EACC: D36.2 (A), D37.2 (A), D38.2 (A), D39.2 (A), D40.2 (A), R42.2, U8.9 (E1), U8.10 (E2)
~FI: D42.2 (A), D43.2 (A), D44.2 (A), D45.2 (A), R43.2, U14.9 (E1), U14.10 (E2)
~IVTBUS: D65.2 (A), R61.2, U23.1 (OEa)
~JH: D60.2 (A), R57.2, U18.9 (~PE)
~JL: D58.2 (A), D59.2 (A), R56.2, U17.9 (~PE)
~LI: D61.2 (A), R58.2, U21.1 (~E)
~MR: U3.10, U12.10 (~R), U12.13 (~R), U17.1 (~MR), U18.1 (~MR)
~WERAM: D62.2 (A), R59.2, U5.2, U7.12, U24.4, U24.5

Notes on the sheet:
Clock
RAM
Power
ALU
Instruction Decoder

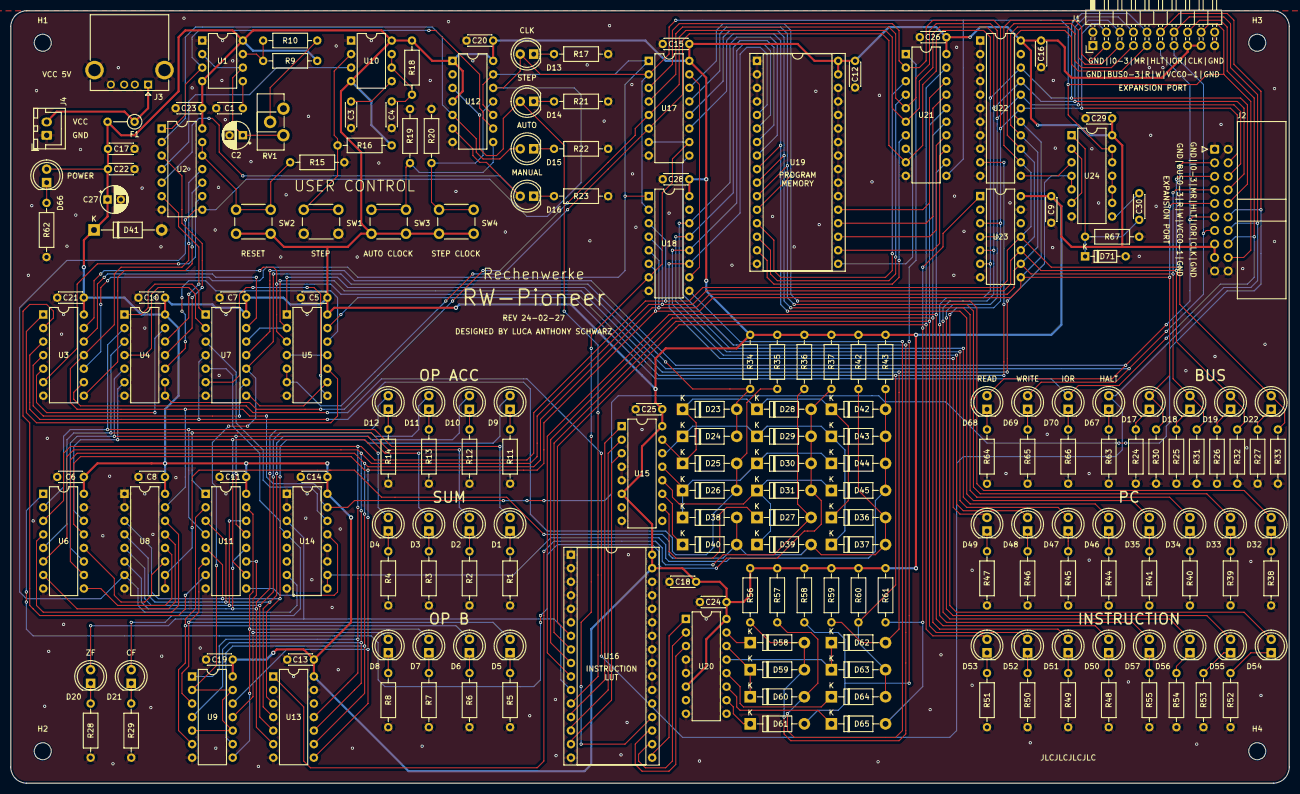
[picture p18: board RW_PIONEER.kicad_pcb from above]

Board: 2 copper layers, 240.0 x 145.0 mm, 206 parts (0 on the bottom side), 168 nets.

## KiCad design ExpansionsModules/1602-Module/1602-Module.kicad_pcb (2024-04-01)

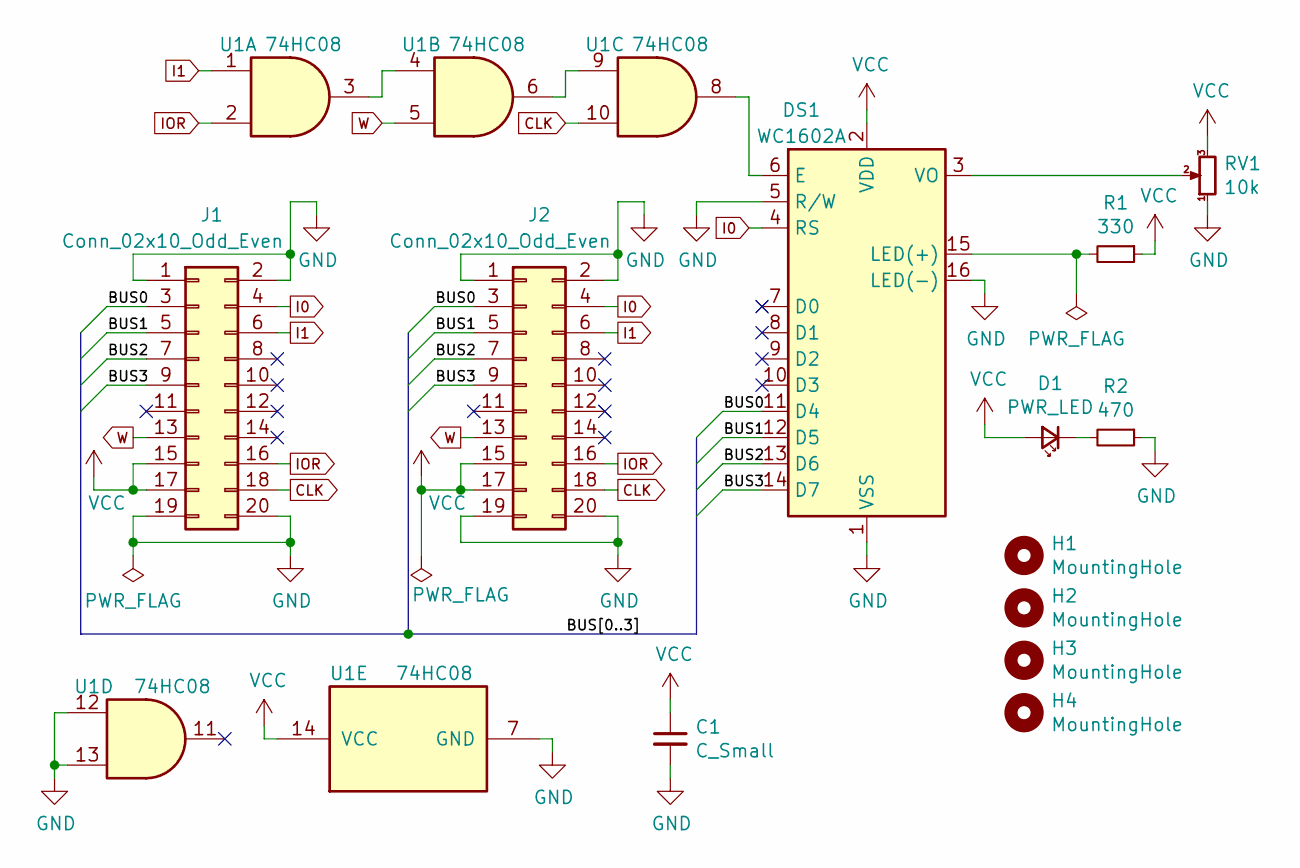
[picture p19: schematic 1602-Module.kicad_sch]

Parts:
C1: C_Small; C_Disc_D4.3mm_W1.9mm_P5.00mm
D1: PWR_LED; LED_D5.0mm_Clear
DS1: WC1602A
H1, H2, H3, H4: MountingHole; MountingHole_3.2mm_M3
J1: Conn_02x10_Odd_Even; IDC-Header_2x10_P2.54mm_Horizontal
J2: Conn_02x10_Odd_Even; PinSocket_2x10_P2.54mm_Horizontal
R1: 330; R_Axial_DIN0207_L6.3mm_D2.5mm_P10.16mm_Horizontal
R2: 470; R_Axial_DIN0207_L6.3mm_D2.5mm_P10.16mm_Horizontal
RV1: 10k; Potentiometer_Piher_PT-10-H01_Horizontal
U1: 74HC08; DIP-14_W7.62mm

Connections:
/BUS0: DS1.11 (D4), J1.3, J2.3
/BUS1: DS1.12 (D5), J1.5, J2.5
/BUS2: DS1.13 (D6), J1.7, J2.7
/BUS3: DS1.14 (D7), J1.9, J2.9
CLK: J1.18, J2.18, U1.10
GND: C1.2, DS1.1 (VSS), DS1.5 (R/W), DS1.16 (LED(-)), J1.1, J1.2, J1.19, J1.20, J2.1, J2.2, J2.19, J2.20, R2.1, RV1.1, U1.7 (GND), U1.12, U1.13
I0: DS1.4 (RS), J1.4, J2.4
I1: J1.6, J2.6, U1.1
IOR: J1.16, J2.16, U1.2
unnamed: D1.1 (K), R2.2
unnamed: DS1.3 (VO), RV1.2
unnamed: DS1.6 (E), U1.8
unnamed: DS1.15 (LED(+)), R1.2
unnamed: U1.3, U1.4
unnamed: U1.6, U1.9
VCC: C1.1, D1.2 (A), DS1.2 (VDD), J1.15, J1.17, J2.15, J2.17, R1.1, RV1.3, U1.14 (VCC)
W: J1.13, J2.13, U1.5

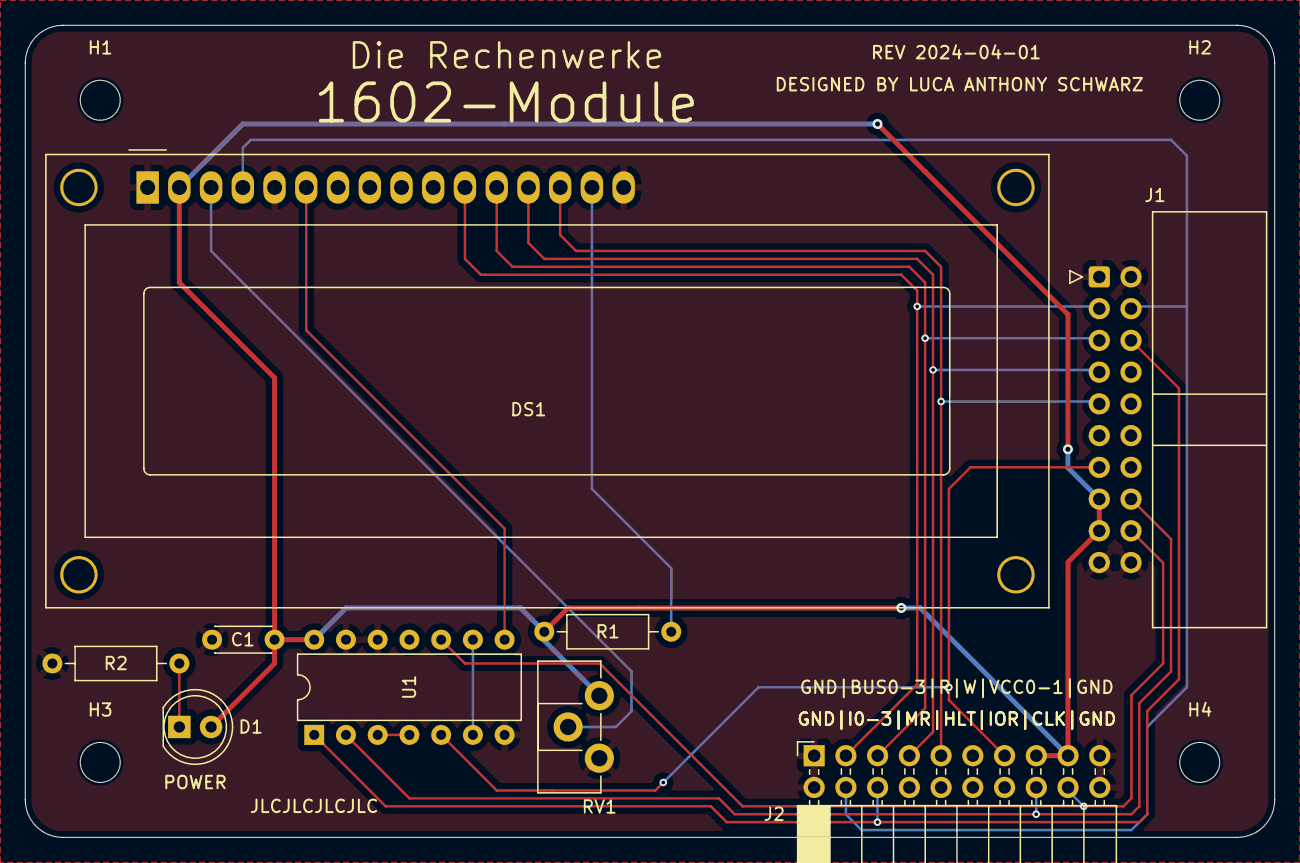
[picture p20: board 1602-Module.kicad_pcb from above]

Board: 2 copper layers, 100.0 x 65.0 mm, 13 parts (0 on the bottom side), 17 nets.

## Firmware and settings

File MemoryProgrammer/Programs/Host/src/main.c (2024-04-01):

#include <ctype.h>
#include <unistd.h>
#include <libserialport.h>
#include <stdio.h>
#include <stdlib.h>
#include <string.h>
#include <time.h>

#define RECEIVE_LINE_MIN_BUF_SIZE 32

int min(int a, int b) {
    return a < b ? a : b;
}

int read_bin_file(const char* file_path, size_t* file_size, char** data) {
    FILE* file = fopen(file_path, "rb");
    fseek(file, 0, SEEK_END);
    *file_size = ftell(file);
    rewind(file);
    *data = (char*)malloc(*file_size);
    fread(data, 1, *file_size, file);
    fclose(file);

    if (data && file_size > 0) {
        return 0;
    }
    return -1;
}

int serial_check(enum sp_return result) {
    char* error_message;
    switch (result) {
    case SP_ERR_ARG:
        fprintf(stderr, "Serial Port Error. Invalid argument\n");
        return SP_ERR_ARG;
    case SP_ERR_FAIL:
        error_message = sp_last_error_message();
        fprintf(stderr, "Serial Port Error. %s\n", error_message);
        sp_free_error_message(error_message);
        return SP_ERR_FAIL;
    case SP_ERR_SUPP:
        fprintf(stderr, "Serial Port Error. Operation not supported\n");
        return SP_ERR_SUPP;
    case SP_ERR_MEM:
        fprintf(stderr, "Serial Port Error. Memory allocation failed\n");
        return SP_ERR_MEM;
    case SP_OK:
        return SP_OK;
    default:
        return 0;
    }
}

int serial_send_data(struct sp_port* port, const char* data, int data_size) {
    if (serial_check(sp_blocking_write(port, data, data_size, 1000)) != 0) {
        return -1;
    }
    if (serial_check(sp_drain(port)) != 0) {
        return -1;
    }
    return 0;
}

int serial_send_byte(struct sp_port* port, char byte) {
    if (serial_check(sp_blocking_write(port, &byte, 1, 1000)) != 0) {
        return -1;
    }
    if (serial_check(sp_drain(port)) != 0) {
        return -1;
    }
    return 0;
}

int serial_receive_string(struct sp_port* port, char** data, size_t* data_size) {
    *data = (char*)malloc(RECEIVE_LINE_MIN_BUF_SIZE * sizeof(char));
    *data_size = 0;
    size_t buffer_size = RECEIVE_LINE_MIN_BUF_SIZE;
    while (1) {
        int serial_input_buf_size = sp_input_waiting(port);
        if (serial_input_buf_size > 0) {
            char next_byte;
            if (serial_check(sp_blocking_read(port, &next_byte, 1, 1000)) != 0) {
                return -1;
            }

            if (buffer_size - *data_size < 1) {
                buffer_size *= 2;
                *data = (char*)realloc(*data, buffer_size);
            }
            
            memcpy(*data + *data_size, &next_byte, 1);
            (*data_size)++;

            if ((*data)[*data_size - 1] == '\0') {
                *data = (char*)realloc(*data, *data_size);
                return 0;
            }
        }
        // Sleep for 1us
        nanosleep((struct timespec[]){{0, 1000L}}, NULL);
    }
}

int operation_str_valid(const char* str) {
    if (strcmp(str, "Program") == 0) {
        return 1;
    } else if (strcmp(str, "Erase") == 0) {
        return 1;
    } else if (strcmp(str, "MemoryDump") == 0) {
        return 1;
    } else {
        return 0;
    }
}

int device_str_valid(const char* str) {
    if (strcmp(str, "AT28C64") == 0) {
        return 1;
    } else if (strcmp(str, "AT28C128") == 0) {
        return 1;
    } else if (strcmp(str, "AT28C256") == 0) {
        return 1;
    } else if (strcmp(str, "SST39SF010A") == 0) {
        return 1;
    } else if (strcmp(str, "SST39SF020A") == 0) {
        return 1;
    } else if (strcmp(str, "SST39SF040") == 0) {
        return 1;
    } else {
        return 0;
    }
}

int scan_serial_ports() {
    struct sp_port** ports;

    int port_list_result = serial_check(sp_list_ports(&ports));
    if (port_list_result != SP_OK) {
        fprintf(stderr, "Finding ports failed!\n");
        return -1;
    }

    printf("Listing available ports:\n\n");

    for (int i = 0; ports[i] != NULL; i++) {
        printf("Port %i\n", i);
        printf("Name: %s\n", sp_get_port_name(ports[i]));
        printf("Description: %s\n", sp_get_port_description(ports[i]));

        enum sp_transport transport = sp_get_port_transport(ports[i]);

        if (transport == SP_TRANSPORT_NATIVE) {
            printf("Type: Native\n");
        } else if (transport == SP_TRANSPORT_USB) {
            printf("Type: USB\n");
            printf("Manufacturer: %s\n", sp_get_port_usb_manufacturer(ports[i]));
            printf("Product: %s\n", sp_get_port_usb_product(ports[i]));
            printf("Serial: %s\n", sp_get_port_usb_serial(ports[i]));

            int vID;
            int pID;
            sp_get_port_usb_vid_pid(ports[i], &vID, &pID);
            printf("VID: %i PID: %i\n", vID, pID);

            int bus;
            int address;
            sp_get_port_usb_bus_address(ports[i], &bus, &address);
            printf("BUS: %i Address: %i\n", bus, address);
        } else if (transport == SP_TRANSPORT_BLUETOOTH) {
            printf("Type: Bluetooth\n");
            printf("MAC: %s\n", sp_get_port_bluetooth_address(ports[i]));
        }
        printf("\n");
    }
    sp_free_port_list(ports);
    return 0;
}

int main(int argc, char* argv[]) {
    printf("Starting RW_FLASH\n");

    char* binary_file_path = NULL;
    char* serial_port_name = NULL;
    char* operation = NULL;
    char* target = NULL;
    int scan_enabled = 0;
    int operation_length = 0;
    int arg;
    while ((arg = getopt(argc, argv, "d:hl:o:p:st:")) != -1) {
        switch (arg) {
        case 'd':
            binary_file_path = optarg;
            break;
        case 'h':
            printf("Help for RW_FLASH\n");
            printf("RW_FLASH is used for programming EEPROM and FLASH ICs. It is meant to be used with the accompanying RW_FLASH_MICRO program to be used with Arduino capable micro constrollers\n");
            printf("Currently supported EEPROMS: AT28C64, AT28C128, AT28C256\n");
            printf("Currently supported FLASH-Devices: SST39SF010A, SST39SF020A, SST39SF040\n");
            printf("Currently supported operations: Program, Erase, MemoryDump\n");
            printf("When programming SST39SF*-Devices the Erase operation needs to be performed before the Program operation as the FLASH memory needs to be empty to be rewritten\n");
            printf("-d => Path to binary data file which contents should be written to memory device. Only used when executing the Program operation\n");
            printf("-h => Displays this help page and application returns\n");
            printf("-l => Optinal size of binary data in bytes to be written to memory device or to be dumped in a MemoryDump operation. If not specified the whole file's content will be written to the device when "
                   "programming. Only used when using the Program and MemoryDump operations.\n");
            printf("-o => Operation to be executed\n");
            printf("-p => Serial port to use for communicating with the micro controller that does the actual programming\n");
            printf("-s => When specified a list of available serial ports will be printed before the application returns\n");
            printf("-t => Programming target. This is one of the supported EEPROMS or FLASH-Devices\n");
            return 0;
        case 'l':
            operation_length = strtol(optarg, NULL, 10);
            break;
        case 'o':
            operation = optarg;
            break;
        case 'p':
            serial_port_name = optarg;
            break;
        case 's':
            scan_enabled = 1;
            break;
        case 't':
            target = optarg;
            break;
        case '?':
            if (isprint(optopt)) {
                fprintf(stderr, "Option -%c unknown\n", optopt);
            } else {
                fprintf(stderr, "Option character -\\x%x unknown\n", optopt);
            }
            return -1;
        default:
            return -1;
        }
    }

    if (scan_enabled) {
        printf("Scanning serial ports\n");
        return scan_serial_ports();
    }

    if (operation == NULL) {
        fprintf(stderr, "Operation not specified. Aborting\n");
        return -1;
    }

    if (serial_port_name == NULL) {
        fprintf(stderr, "Serial port not specified. Aborting\n");
        return -1;
    }

    if (target == NULL) {
        fprintf(stderr, "Target not specified. Aborting\n");
        return -1;
    }

    size_t binary_data_size = 0;
    char* binary_data = NULL;
    if (strcmp(operation, "Program") == 0) {
        if (binary_file_path == NULL) {
            fprintf(stderr, "Path to binary data file not specified. Aborting\n");
            return -1;
        }
        if (read_bin_file(binary_file_path, &binary_data_size, &binary_data) != 0) {
            fprintf(stderr, "Error while reading binary data file. Aborting\n");
            return -1;
        }
    } else if (strcmp(operation, "Erase") != 0 && strcmp(operation, "MemoryDump") != 0) {
        fprintf(stderr, "Specified operation %s unknown. Aborting\n", operation);
        return -1;
    }

    if(operation_length <= 0) {
        operation_length = binary_data_size;
    }

    struct sp_port** ports;
    int port_list_result = serial_check(sp_list_ports(&ports));
    if (port_list_result != SP_OK) {
        fprintf(stderr, "Finding ports failed!\n");
        return -1;
    }

    int selected_port_index = -1;
    for (int i = 0; ports[i] != NULL; i++) {
        if (strcmp(serial_port_name, sp_get_port_name(ports[i])) == 0) {
            selected_port_index = i;
        }
    }

    if (selected_port_index == -1) {
        fprintf(stderr, "Sepcified serial port %s invalid. Aborting\n", serial_port_name);
        sp_free_port_list(ports);
        return -1;
    }

    struct sp_port* port;
    sp_copy_port(ports[selected_port_index], &port);
    sp_free_port_list(ports);

    serial_check(sp_open(port, SP_MODE_READ_WRITE));
    serial_check(sp_set_baudrate(port, 9600));
    serial_check(sp_set_bits(port, 8));
    serial_check(sp_set_parity(port, SP_PARITY_NONE));
    serial_check(sp_set_stopbits(port, 1));
    serial_check(sp_set_flowcontrol(port, SP_FLOWCONTROL_NONE));
    serial_check(sp_flush(port, SP_BUF_INPUT));

    printf("Serial port opened\n");

    int operation_completed = 0;
    int current_address = 0;
    while (!operation_completed) {
        char* line = NULL;
        size_t line_size = 0;
        serial_receive_string(port, &line, &line_size);

        printf("Received: %s\n", line);

        if (strcmp(line, "Send operation") == 0) {
            printf("Sending operation %s\n", operation);
            serial_send_data(port, operation, strlen(operation) + 1);
        } else if (strcmp(line, "Send target") == 0) {
            printf("Sending target %s\n", target);
            serial_send_data(port, target, strlen(target) + 1);
        } else if(strcmp(line, "Send operation range") == 0) {
            int str_length = snprintf(NULL, 0, "%i", operation_length);
            char operation_length_str[str_length + 1];
            snprintf(operation_length_str, str_length + 2, "%i", operation_length);
            operation_length_str[str_length] = '\0';
            printf("Sending operation range %s\n", operation_length_str);
            serial_send_data(port, operation_length_str, str_length + 1);
        } else if (strcmp(line, "Send next byte") == 0 && current_address < binary_data_size) {
            printf("Sending next byte %x\n", binary_data[current_address]);
            serial_send_byte(port, binary_data[current_address]);
            current_address++;
        } else if (strcmp(line, "Operation completed") == 0) {
            operation_completed = 1;
        }
        // Sleep for 1us
        nanosleep((struct timespec[]){{0, 1000L}}, NULL);
    }

    printf("Closing port\n");

    serial_check(sp_close(port));
    sp_free_port(port);
    return 0;
}

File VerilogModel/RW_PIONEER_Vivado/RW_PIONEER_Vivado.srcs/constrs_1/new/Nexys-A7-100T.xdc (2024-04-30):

## This file is a general .xdc for the Nexys A7-100T
## To use it in a project:
## - uncomment the lines corresponding to used pins
## - rename the used ports (in each line, after get_ports) according to the top level signal names in the project

## Clock signal
set_property -dict {PACKAGE_PIN E3 IOSTANDARD LVCMOS33} [get_ports CLK100MHZ]
create_clock -period 10.000 -name sys_clk_pin -waveform {0.000 5.000} -add [get_ports CLK100MHZ]


##Switches
#set_property -dict { PACKAGE_PIN J15   IOSTANDARD LVCMOS33 } [get_ports { SW[0] }]; #IO_L24N_T3_RS0_15 Sch=sw[0]
#set_property -dict { PACKAGE_PIN L16   IOSTANDARD LVCMOS33 } [get_ports { SW[1] }]; #IO_L3N_T0_DQS_EMCCLK_14 Sch=sw[1]
#set_property -dict { PACKAGE_PIN M13   IOSTANDARD LVCMOS33 } [get_ports { SW[2] }]; #IO_L6N_T0_D08_VREF_14 Sch=sw[2]
#set_property -dict { PACKAGE_PIN R15   IOSTANDARD LVCMOS33 } [get_ports { SW[3] }]; #IO_L13N_T2_MRCC_14 Sch=sw[3]
#set_property -dict { PACKAGE_PIN R17   IOSTANDARD LVCMOS33 } [get_ports { SW[4] }]; #IO_L12N_T1_MRCC_14 Sch=sw[4]
#set_property -dict { PACKAGE_PIN T18   IOSTANDARD LVCMOS33 } [get_ports { SW[5] }]; #IO_L7N_T1_D10_14 Sch=sw[5]
#set_property -dict { PACKAGE_PIN U18   IOSTANDARD LVCMOS33 } [get_ports { SW[6] }]; #IO_L17N_T2_A13_D29_14 Sch=sw[6]
#set_property -dict { PACKAGE_PIN R13   IOSTANDARD LVCMOS33 } [get_ports { SW[7] }]; #IO_L5N_T0_D07_14 Sch=sw[7]
#set_property -dict { PACKAGE_PIN T8    IOSTANDARD LVCMOS18 } [get_ports { SW[8] }]; #IO_L24N_T3_34 Sch=sw[8]
#set_property -dict { PACKAGE_PIN U8    IOSTANDARD LVCMOS18 } [get_ports { SW[9] }]; #IO_25_34 Sch=sw[9]
#set_property -dict { PACKAGE_PIN R16   IOSTANDARD LVCMOS33 } [get_ports { SW[10] }]; #IO_L15P_T2_DQS_RDWR_B_14 Sch=sw[10]
#set_property -dict { PACKAGE_PIN T13   IOSTANDARD LVCMOS33 } [get_ports { SW[11] }]; #IO_L23P_T3_A03_D19_14 Sch=sw[11]
#set_property -dict { PACKAGE_PIN H6    IOSTANDARD LVCMOS33 } [get_ports { SW[12] }]; #IO_L24P_T3_35 Sch=sw[12]
#set_property -dict { PACKAGE_PIN U12   IOSTANDARD LVCMOS33 } [get_ports { SW[13] }]; #IO_L20P_T3_A08_D24_14 Sch=sw[13]
#set_property -dict { PACKAGE_PIN U11   IOSTANDARD LVCMOS33 } [get_ports { SW[14] }]; #IO_L19N_T3_A09_D25_VREF_14 Sch=sw[14]
#set_property -dict { PACKAGE_PIN V10   IOSTANDARD LVCMOS33 } [get_ports { SW[15] }]; #IO_L21P_T3_DQS_14 Sch=sw[15]

## LEDs
#set_property -dict {PACKAGE_PIN H17 IOSTANDARD LVCMOS33} [get_ports {LED[0]}]
#set_property -dict {PACKAGE_PIN K15 IOSTANDARD LVCMOS33} [get_ports {LED[1]}]
#set_property -dict {PACKAGE_PIN J13 IOSTANDARD LVCMOS33} [get_ports {LED[2]}]
#set_property -dict {PACKAGE_PIN N14 IOSTANDARD LVCMOS33} [get_ports {LED[3]}]
#set_property -dict { PACKAGE_PIN R18   IOSTANDARD LVCMOS33 } [get_ports { LED[4] }]; #IO_L7P_T1_D09_14 Sch=led[4]
#set_property -dict { PACKAGE_PIN V17   IOSTANDARD LVCMOS33 } [get_ports { LED[5] }]; #IO_L18N_T2_A11_D27_14 Sch=led[5]
#set_property -dict { PACKAGE_PIN U17   IOSTANDARD LVCMOS33 } [get_ports { LED[6] }]; #IO_L17P_T2_A14_D30_14 Sch=led[6]
#set_property -dict { PACKAGE_PIN U16   IOSTANDARD LVCMOS33 } [get_ports { LED[7] }]; #IO_L18P_T2_A12_D28_14 Sch=led[7]
#set_property -dict { PACKAGE_PIN V16   IOSTANDARD LVCMOS33 } [get_ports { LED[8] }]; #IO_L16N_T2_A15_D31_14 Sch=led[8]
#set_property -dict { PACKAGE_PIN T15   IOSTANDARD LVCMOS33 } [get_ports { LED[9] }]; #IO_L14N_T2_SRCC_14 Sch=led[9]
#set_property -dict { PACKAGE_PIN U14   IOSTANDARD LVCMOS33 } [get_ports { LED[10] }]; #IO_L22P_T3_A05_D21_14 Sch=led[10]
#set_property -dict { PACKAGE_PIN T16   IOSTANDARD LVCMOS33 } [get_ports { LED[11] }]; #IO_L15N_T2_DQS_DOUT_CSO_B_14 Sch=led[11]
#set_property -dict { PACKAGE_PIN V15   IOSTANDARD LVCMOS33 } [get_ports { LED[12] }]; #IO_L16P_T2_CSI_B_14 Sch=led[12]
#set_property -dict { PACKAGE_PIN V14   IOSTANDARD LVCMOS33 } [get_ports { LED[13] }]; #IO_L22N_T3_A04_D20_14 Sch=led[13]
#set_property -dict { PACKAGE_PIN V12   IOSTANDARD LVCMOS33 } [get_ports { LED[14] }]; #IO_L20N_T3_A07_D23_14 Sch=led[14]
#set_property -dict { PACKAGE_PIN V11   IOSTANDARD LVCMOS33 } [get_ports { LED[15] }]; #IO_L21N_T3_DQS_A06_D22_14 Sch=led[15]

## RGB LEDs
#set_property -dict { PACKAGE_PIN R12   IOSTANDARD LVCMOS33 } [get_ports { LED16_B }]; #IO_L5P_T0_D06_14 Sch=led16_b
#set_property -dict { PACKAGE_PIN M16   IOSTANDARD LVCMOS33 } [get_ports { LED16_G }]; #IO_L10P_T1_D14_14 Sch=led16_g
#set_property -dict { PACKAGE_PIN N15   IOSTANDARD LVCMOS33 } [get_ports { LED16_R }]; #IO_L11P_T1_SRCC_14 Sch=led16_r
#set_property -dict { PACKAGE_PIN G14   IOSTANDARD LVCMOS33 } [get_ports { LED17_B }]; #IO_L15N_T2_DQS_ADV_B_15 Sch=led17_b
#set_property -dict { PACKAGE_PIN R11   IOSTANDARD LVCMOS33 } [get_ports { LED17_G }]; #IO_0_14 Sch=led17_g
#set_property -dict { PACKAGE_PIN N16   IOSTANDARD LVCMOS33 } [get_ports { LED17_R }]; #IO_L11N_T1_SRCC_14 Sch=led17_r
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

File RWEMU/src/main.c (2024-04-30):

#include <stdbool.h>
#include <stdio.h>

enum instructions {
    LDI = 0,
    LDA,
    STOA,
    STOB,
    ADD,
    ADDI,
    ADDC,
    SUB,
    SUBI,
    SUBC,
    JMP,
    LJMP,
    BNEZ,
    BEZ,
    HALT,
    NOOP
};

int main(int argc, char* argv[]) {
    unsigned char program[256];
    for (unsigned int i = 0; i < 256; i++) {
        program[i] = 0b11110000;
    }

    //Fn = 3 2 1 0
    //Fn+1 = 7 6 5 4
    //Temp = 9 8
    //Count = 11 10
    //Out = 12 13 14 15

    // Fibonacci

    // Init memory
    program[0] = LDI << 4 | 0; //LDI 0
    program[1] = STOA << 4 | 0; //STOA 0
    program[2] = STOA << 4 | 1; //STOA 1
    program[3] = STOA << 4 | 2; //STOA 2
    program[4] = STOA << 4 | 3; //STOA 3
    program[5] = STOA << 4 | 5; //STOA 5
    program[6] = STOA << 4 | 6; //STOA 6
    program[7] = STOA << 4 | 7; //STOA 7
    program[8] = STOA << 4 | 8; //STOA 8
    program[9] = STOA << 4 | 9; //STOA 9
    program[10] = STOA << 4 | 10; //STOA 10
    program[11] = STOA << 4 | 11; //STOA 11
    program[12] = STOA << 4 | 12; //STOA 12
    program[13] = STOA << 4 | 13; //STOA 13
    program[14] = STOA << 4 | 14; //STOA 14
    program[15] = STOA << 4 | 15; //STOA 15
    program[16] = LDI << 4 | 1; //LDI 1
    program[17] = STOA << 4 | 4; //STOA 4

    // Increase counter
    program[18] = LDA << 4 | 10; //LDA 10
    program[19] = ADDI << 4 | 1; //ADDI 1
    program[20] = STOA << 4 | 10; //STOA 10
    program[21] = LDI << 4 | 0; //LDI 0
    program[22] = ADDC << 4 | 11; //ADDC 11
    program[23] = STOA << 4 | 11; //STOA 11

    // Compute next fib number
    program[24] = LDA << 4 | 0; //LDA 0
    program[25] = ADD << 4 | 4; //ADD 4
    program[26] = STOA << 4 | 0; //STOA 0
    program[27] = LDA << 4 | 1; //LDA 1
    program[28] = ADDC << 4 | 5; //ADDC 5
    program[29] = STOA << 4 | 1; //STOA 1
    program[30] = LDA << 4 | 2; //LDA 2
    program[31] = ADDC << 4 | 6; //ADDC 6
    program[32] = STOA << 4 | 2; //STOA 2
    program[33] = LDA << 4 | 3; //LDA 3
    program[34] = ADDC << 4 | 7; //ADDC 7
    program[35] = STOA << 4 | 3; //STOA 3

    // Swap numbers
    program[36] = LDA << 4 | 0; //LDA 0
    program[37] = STOA << 4 | 8; //STOA 8
    program[38] = LDA << 4 | 4; //LDA 4
    program[39] = STOA << 4 | 0; //STOA 0
    program[40] = LDA << 4 | 8; //LDA 8
    program[41] = STOA << 4 | 4; //STOA 4

    program[42] = LDA << 4 | 1; //LDA 1
    program[43] = STOA << 4 | 8; //STOA 8
    program[44] = LDA << 4 | 5; //LDA 5
    program[45] = STOA << 4 | 1; //STOA 1
    program[46] = LDA << 4 | 8; //LDA 8
    program[47] = STOA << 4 | 5; //STOA 5

    program[48] = LDA << 4 | 2; //LDA 2
    program[49] = STOA << 4 | 8; //STOA 8
    program[50] = LDA << 4 | 6; //LDA 6
    program[51] = STOA << 4 | 2; //STOA 2
    program[52] = LDA << 4 | 8; //LDA 8
    program[53] = STOA << 4 | 6; //STOA 6

    program[54] = LDA << 4 | 3; //LDA 3
    program[55] = STOA << 4 | 8; //STOA 8
    program[56] = LDA << 4 | 7; //LDA 7
    program[57] = STOA << 4 | 3; //STOA 3
    program[58] = LDA << 4 | 8; //LDA 8
    program[59] = STOA << 4 | 7; //STOA 7

    // Output current last fib number to hex display
    program[60] = LDA << 4 | 4; //LDA 4
    program[61] = STOA << 4 | 15; //STOA 15
    program[62] = LDA << 4 | 5; //LDA 5
    program[63] = STOA << 4 | 14; //STOA 14
    program[64] = LDA << 4 | 6; //LDA 6
    program[65] = STOA << 4 | 13; //STOA 13
    program[66] = LDA << 4 | 7; //LDA 7
    program[67] = STOA << 4 | 12; //STOA 12

    // Check counter and jump back if necessary
    program[68] = LDI << 4 | 7; //LDI 7
    program[69] = SUB << 4 | 10; //SUB 10
    program[70] = LDI << 4 | 1; //LDI 1
    program[71] = BNEZ << 4 | 2; //BNEZ 2
    program[72] = LDI << 4 | 1; //LDI 1
    program[73] = SUBC << 4 | 11; //SUBC 11
    program[74] = LDI << 4 | 1; //LDI 1
    program[75] = BNEZ << 4 | 2; //BNEZ 2

    // End of program
    program[76] = HALT << 4 | 15; //HLT 15

    // Merry christmas
    // Command = 14
    // Data = 15

    // Function set
    /*program[0] = LDI << 4 | 3; //LDI 3
    program[1] = STOA << 4 | 14; //STOA 14
    program[2] = LDI << 4 | 3; //LDI 3
    program[3] = STOA << 4 | 14; //STOA 14
    program[4] = LDI << 4 | 3; //LDI 3
    program[5] = STOA << 4 | 14; //STOA 14
    program[6] = LDI << 4 | 2; //LDI 2
    program[7] = STOA << 4 | 14; //STOA 14
    program[8] = LDI << 4 | 2; //LDI 2
    program[9] = STOA << 4 | 14; //STOA 14
    program[10] = LDI << 4 | 8; //LDI 8
    program[11] = STOA << 4 | 14; //STOA 14

    // Clear
    program[12] = LDI << 4 | 0; //LDI 0
    program[13] = STOA << 4 | 14; //STOA 14
    program[14] = LDI << 4 | 1; //LDI 1
    program[15] = STOA << 4 | 14; //STOA 14

    // Display and cursor on
    program[16] = LDI << 4 | 0; //LDI 0
    program[17] = STOA << 4 | 14; //STOA 14
    program[18] = LDI << 4 | 15; //LDI 15
    program[19] = STOA << 4 | 14; //STOA 14

    // Set entry mode
    program[20] = LDI << 4 | 0; //LDI 0
    program[21] = STOA << 4 | 14; //STOA 14
    program[22] = LDI << 4 | 6; //LDI 6
    program[23] = STOA << 4 | 14; //STOA 14

    // Send character data
    // F
    program[24] = LDI << 4 | 4; //LDI 4
    program[25] = STOA << 4 | 15; //STOA 15
    program[26] = LDI << 4 | 6; //LDI 6
    program[27] = STOA << 4 | 15; //STOA 15

    // r
    program[28] = LDI << 4 | 7; //LDI 7
    program[29] = STOA << 4 | 15; //STOA 15
    program[30] = LDI << 4 | 2; //LDI 2
    program[31] = STOA << 4 | 15; //STOA 15

    // o
    program[32] = LDI << 4 | 6; //LDI 6
    program[33] = STOA << 4 | 15; //STOA 15
    program[34] = LDI << 4 | 15; //LDI 15
    program[35] = STOA << 4 | 15; //STOA 15

    // h
    program[36] = LDI << 4 | 6; //LDI 6
    program[37] = STOA << 4 | 15; //STOA 15
    program[38] = LDI << 4 | 8; //LDI 8
    program[39] = STOA << 4 | 15; //STOA 15

    // e
    program[40] = LDI << 4 | 6; //LDI 6
    program[41] = STOA << 4 | 15; //STOA 15
    program[42] = LDI << 4 | 5; //LDI 5
    program[43] = STOA << 4 | 15; //STOA 15

    // Change row
    program[44] = LDI << 4 | 12; //LDI 12
    program[45] = STOA << 4 | 14; //STOA 14
    program[46] = LDI << 4 | 0; //LDI 0
    program[47] = STOA << 4 | 14; //STOA 14

    // Send character data
    // W
    program[48] = LDI << 4 | 5; //LDI 5
    program[49] = STOA << 4 | 15; //STOA 15
    program[50] = LDI << 4 | 7; //LDI 7
    program[51] = STOA << 4 | 15; //STOA 15

    // e
    program[52] = LDI << 4 | 6; //LDI 6
    program[53] = STOA << 4 | 15; //STOA 15
    program[54] = LDI << 4 | 5; //LDI 5
    program[55] = STOA << 4 | 15; //STOA 15

    // i
    program[56] = LDI << 4 | 6; //LDI 6
    program[57] = STOA << 4 | 15; //STOA 15
    program[58] = LDI << 4 | 9; //LDI 9
    program[59] = STOA << 4 | 15; //STOA 15

    // h
    program[60] = LDI << 4 | 6; //LDI 6
    program[61] = STOA << 4 | 15; //STOA 15
    program[62] = LDI << 4 | 8; //LDI 8
    program[63] = STOA << 4 | 15; //STOA 15
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
